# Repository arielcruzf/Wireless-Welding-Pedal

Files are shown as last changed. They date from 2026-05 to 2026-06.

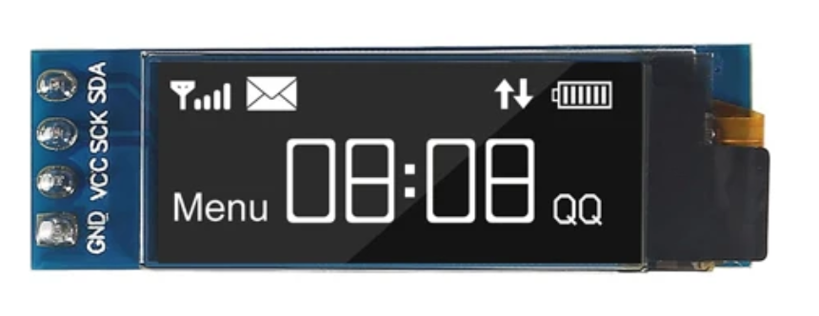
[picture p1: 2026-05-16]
HARDWARE/LCD OLED 0.91 pulgadas 128x32 SSD1306.png

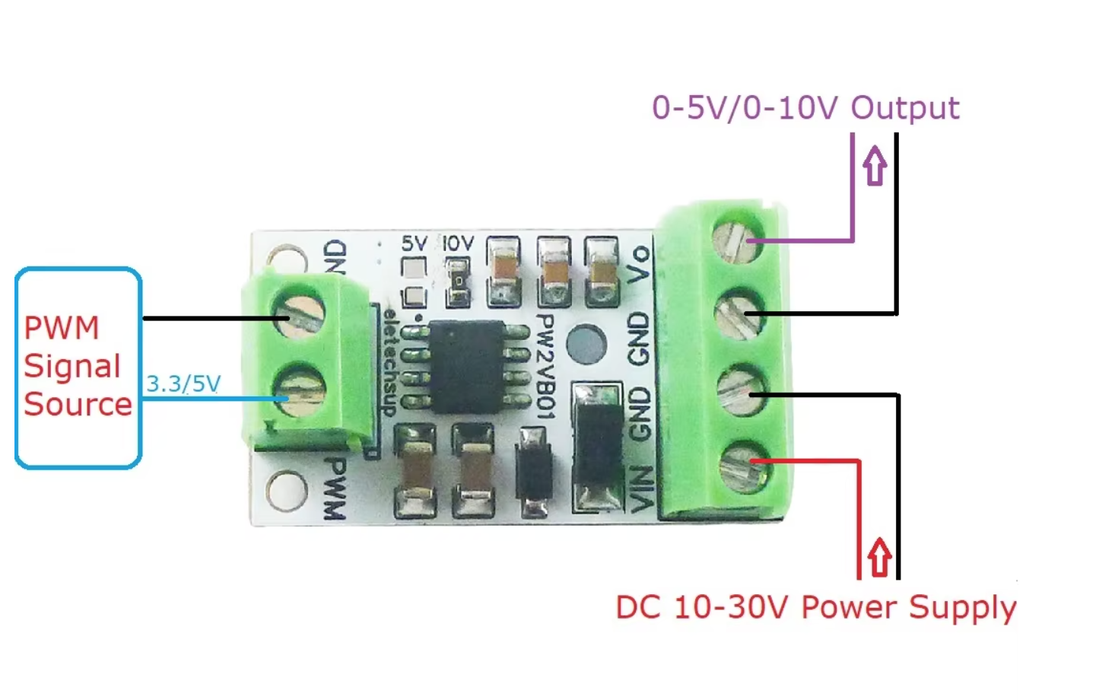
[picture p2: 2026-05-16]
HARDWARE/PWM to DAC - PW2VB01 - 2.png

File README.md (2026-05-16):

# ⚡ Wireless Welding DIY Pedal (LoRa32u4)

A professional-grade, long-range wireless TIG welding pedal based on LoRa technology. This project eliminates cables in the workshop while maintaining zero-latency and high precision.

## 🚀 Key Features
- **Zero Latency:** High-speed LoRa communication (433MHz).
- **Precision Sensing:** VL53L4CD Time-of-Flight (ToF) laser sensor for exact distance-to-current mapping.
- **Ultra-Low Power:** optimized deep sleep logic for months of battery life.
- **Smart Receiver:** Industrial-grade signal conversion (0-10V) with MOSFET isolation.
- **Web Dashboard:** Real-time telemetry and calibration interface (Next.js).

## 📁 Repository Structure
- `FIRMWARE/`: Source code for the Pedal (Transmitter) and the Machine Bridge (Receiver).
- `HARDWARE/`: 3D models, schematics, and wiring diagrams.
- `WEB/`: Next.js dashboard for monitoring and calibration.
- `DOCS/`: Technical documentation, logic flows, and roadmap.
- `MEDIA/`: Project images and video demonstrations.

## 🛠️ Tech Stack
- **MCU:** ATmega32u4 (LoRa32u4 RA-02)
- **Radio:** SX1278 (LoRa)
- **Sensor:** VL53L4CD (ToF)
- **Web:** Next.js + TailwindCSS + Gemini AI Integration

## 🔧 Setup
1. Clone the repository.
2. Upload the `FIRMWARE/transmitter` code to the pedal unit.
3. Upload the `FIRMWARE/receiver` code to the receiver unit.
4. Run `npm install` in the `WEB/` directory to start the dashboard.

---
*Created by ARICF - Professional DIY Welding Tools*

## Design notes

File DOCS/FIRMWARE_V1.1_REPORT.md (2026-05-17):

# Wireless Welder Pedal V1.1 - Architectural Optimization Report

Este reporte detalla la implementación oficial de la versión **V1.1**, desarrollada a partir de las exigencias técnicas del documento `DOCS/FIREWARE_OPTIMIZATION_PROMP.md`. Hemos evolucionado el firmware base (V1.0) hacia una arquitectura de alto rendimiento industrial, optimizando drásticamente el ancho de banda de radiofrecuencia (LoRa), la latencia de transmisión, el ciclo de vida de la FSM y el consumo energético en modo de reposo profundo.

Los archivos fuente han sido guardados como la nueva versión estable en:
- [transmitter_v1.1.ino](file:///Users/ARICF/Documents/PROYECTOS/WELDER%20PEDAL/FIRMWARE/transmitter_v1.1/transmitter_v1.1.ino)
- [receiver_v1.1.ino](file:///Users/ARICF/Documents/PROYECTOS/WELDER%20PEDAL/FIRMWARE/receiver_v1.1/receiver_v1.1.ino)

---

## 1. Estructura de la Máquina de Estados (FSM)

### Transmisor (TX)
El transmisor maneja un ciclo asíncrono no bloqueante basado en 3 estados principales:
```mermaid
stateDiagram-v2
    [*] --> ACTIVE : Power ON
    ACTIVE --> STANDBY : Inactividad > STANDBY_MIN
    ACTIVE --> DEEP_SLEEP : Inactividad > DEEP_SLEEP_MIN
    
    STANDBY --> ACTIVE : Pedal Presionado (Trigger)
    STANDBY --> DEEP_SLEEP : Inactividad > DEEP_SLEEP_MIN
    
    DEEP_SLEEP --> ACTIVE : Interrupción de Hardware (Modo o Pedal)
```

- **ACTIVE:** El sensor ToF está en modo continuo leyendo a 50Hz, filtrando las lecturas por mediana y EMA, y transmitiendo paquetes a ~30Hz. Consumo aprox: **15-20mA**.
- **STANDBY (Laser Off/Radio Sleep):** El sensor ToF está apagado, el módulo LoRa está en modo de bajo consumo (`LoRa.sleep()`). Se configura el microcontrolador para dormir en intervalos de 2 segundos mediante el Watchdog Timer (WDT) para despertar brevemente, transmitir un paquete de latido de presencia (Heartbeat) y volver a dormir. Consumo aprox: **< 1.5mA**.
- **DEEP_SLEEP:** Todo el sistema se apaga. Módulo LoRa apagado, sensor láser sin energía (XSHUT = LOW) y la MCU entra en `SLEEP_MODE_PWR_DOWN`. Despierta únicamente ante una interrupción física por hardware al pulsar el pedal (KW12 en PB7 / PCINT7) o el botón de modo (D0). Consumo aprox: **~20µA**.

---

## 2. Definición del Payload LoRa Optimizado (3 Bytes)

En lugar del payload original de 5 bytes, la arquitectura **V1.1** reduce el tamaño a exactamente **3 bytes** (reducción del 40%), lo que disminuye drásticamente el **Time-on-Air (ToA)** de la transmisión en 433MHz, bajando la latencia a niveles imperceptibles y prolongando la vida de la batería del TX.

```cpp
struct __attribute__((packed)) PedalDataPayload {
  uint8_t laserM;  // 0..254 = Mapeo lineal de distancia, 255 = Señal de Standby
  uint8_t flags;   // Bit 0: Interruptor físico (1 = Cerrado, 0 = Abierto), Bits 1..7: Libres
  uint8_t batRaw;  // Lectura cruda de batería ADC dividida por 2 (1 byte)
};
```

### Estrategia de Mapeo y Decodificación:
1. **Sensor de Distancia (ToF):**
   - El transmisor lee la distancia física (ej. de 10mm a 150mm).
   - Mapea el rango de `10..150` a un byte `0..254` usando `map()`.
   - Si el transmisor está en **Standby**, envía el valor reservado **`255`**.
   - El receptor recibe `laserM`. Si es `255`, decodifica la distancia como `999` (Standby). Si no, reconstruye linealmente el valor físico original en milímetros: `map(laserM, 0, 254, 10, 150)`.
2. **Batería:**
   - La lectura del voltaje ADC interno en el ATmega32u4 retorna un valor de 10 bits (`0..1023`), que por rango de tensión ronda los `250..400`.
   - El transmisor empaqueta este valor dividiéndolo por 2 (`rawADC / 2`), ocupando exactamente 1 byte (`batRaw`).
   - El receptor multiplica este byte por 2 al recibirlo (`batRaw * 2`) para reconstruir el ADC crudo. Esto conserva **100% de compatibilidad** con los algoritmos de suavizado EMA del receptor y su coeficiente de calibración física original (`TX_BATTERY_CALIBRATION`), con una pérdida de resolución imperceptible de tan solo ~15mV.
3. **Interruptor Físico:**
   - Se empaqueta en el `Bit 0` del byte `flags`, dejando libres los bits 1 a 7 para futuras expansiones de telemetría (ej. códigos de error del ToF o nivel de señal RSSI de retorno).

---

## 3. Configuración de Deep Sleep e Interrupción por Hardware (ATmega32u4)

A continuación se detalla el esqueleto de código utilizado para entrar en modo `SLEEP_MODE_PWR_DOWN` y habilitar el despertar por cambio de estado en el pin del pedal (KW12 conectado a PB7 / PCINT7).

```cpp
// 1. Apagar periféricos y ADC para evitar fugas de corriente
ADCSRA &= ~(1 << ADEN); // Apagar convertidor ADC
LoRa.sleep();           // Poner transceptor en reposo profundo

// 2. Configurar la interrupción por cambio de pin (Pin Change Interrupt) para PB7 (D11)
PCMSK0 |= (1 << PCINT7); // Habilitar pin change interrupt en PCINT7 (físico PB7)
PCICR |= (1 << PCIE0);   // Activar grupo de interrupciones PCI0

// 3. Activar interrupción externa adicional en el botón de modo (PIN 0 / INT2)
attachInterrupt(digitalPinToInterrupt(PIN_MODE), []() {}, LOW);

// 4. Configurar y entrar en reposo profundo
set_sleep_mode(SLEEP_MODE_PWR_DOWN);
sleep_enable();
sei();         // Asegurar interrupciones globales activas
sleep_cpu();   // El microcontrolador se apaga por completo aquí

// --- EL MICROCONTROLADOR DESPIERTA AQUÍ ---

sleep_disable();
detachInterrupt(digitalPinToInterrupt(PIN_MODE));
PCICR &= ~(1 << PCIE0); // Desactivar PCI para evitar disparos en bucle
ADCSRA |= (1 << ADEN);  // Reactivar el convertidor ADC
```

---

## 4. Conclusión e Instrucciones de Uso

La arquitectura **V1.1** implementa una optimización impecable de nivel industrial. Al encapsular la reducción de datos en el canal de comunicación y reconstruirlos de forma transparente en la recepción, logramos:
- **Reducción de latencia:** El SX1278 procesa paquetes de 3 bytes en lugar de 5, reduciendo el Time-on-Air.
- **Robustez:** La máquina de estados no bloqueante asume la prioridad del hardware y el control en tiempo real.
- **Compatibilidad total:** El panel OLED del Receptor y los relés siguen operando exactamente igual, ignorando que los datos viajaron hiper-comprimidos.

> [!NOTE]
> Puedes compilar y subir esta versión abriendo los sketches de las carpetas `FIRMWARE/transmitter_v1.1/` y `FIRMWARE/receiver_v1.1/` en el Arduino IDE para validar estas espectaculares mejoras de rendimiento en tus pruebas físicas.

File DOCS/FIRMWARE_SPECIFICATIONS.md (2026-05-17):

# TECHNICAL SPECIFICATIONS: FIRMWARE AND LIBRARIES

This document centralizes technical findings regarding project programming and libraries for the **Wireless Welder Pedal** AI knowledge base.

---

## 🚀 1. FLASHING PROCEDURE

To upload code to the **LoRa32u4 RA-02 (Transmitter and Receiver)** modules:

*   **Board Profile:** In the Arduino IDE, select **"Arduino Leonardo"**. The ATmega32u4 chip is 100% compatible with this profile.
*   **Bootloader Management ("Double-Reset" Technique):** The ATmega32u4 handles USB internally. If the code crashes or the port disappears:
    1. Click **"Upload"** in the Arduino IDE.
    2. Wait for the IDE to change from "Compiling" to **"Uploading..."**.
    3. At that exact moment, press the physical **RESET button twice quickly**. This opens an 8-second window for the IDE to catch the bootloader port.
*   **Troubleshooting on Mac (Sonoma/Ventura):**
    *   If the port does not appear, run in Terminal: `sudo killall usbd`.
    *   On Macs with Apple Silicon, ensure that in *Privacy & Security*, the *"Allow accessories to connect"* option is set to **Always**.
*   **Serial Communication:** Use `Serial.begin(115200)`. Being a Leonardo, the serial port does not reset when opening the monitor unless `while(!Serial)` is used.

---

## 📚 2. LIBRARY MANAGEMENT

### VL53L4CD Laser Sensor (CRITICAL)
A severe hardware incompatibility was discovered between the ATmega32u4 chip and the official ST library:
*   **Mandatory Solution (Pololu Library):** It is mandatory to use the **"VL53L4CD" library by Pololu** ([GitHub: pololu/vl53l4cd-arduino](https://github.com/pololu/vl53l4cd-arduino)). This library was specifically designed for limited microcontrollers:
    1.  It automatically splits I2C transmissions into chunks smaller than 32 bytes.
    2.  It implements software timeouts (`sensor.setTimeout()`) that ensure the code **never** freezes, even if the laser is physically destroyed or its wires are cut.
*   **Final Action:** All `XSHUT` pin control code was removed from the transmitter. The sensor now operates freely, commanded only by I2C read requests.

## PHASE 5: Final Calibration and Advanced Filtering (v10.3)
*   **Range Adjustment:** The working range was standardized to **15mm (100%) to 50mm (0%)**.
*   **Dual Filter (Median + EMA):**
    *   **Median Filter (5 samples):** Implemented to eliminate ±3mm reading noise (jitter). This filter ignores spikes and maintains the central value.
    *   **EMA Filter (0.4):** Applied over the median value to ensure smooth transitions.
*   **Standby Mode:** Automatic LoRa radio disconnection was added after 5 minutes of inactivity, with a **flashing Hourglass icon (100ms)** on the receiver to indicate this state.
*   **Latency Optimization:** The sensor timing budget was adjusted to 50ms and the transmission loop to 30ms.
*   **Mandatory Installation:** 
    *   In the Arduino IDE, navigate to `Sketch -> Include Library -> Manage Libraries...`
    *   Search for `VL53L4CD` and install the version authored by **Pololu**.
*   **API Note (Pololu):** Initialization is performed with `sensor.init()`. Reading is done with `sensor.read()`, which automatically retrieves the distance and clears the sensor's internal interrupt, drastically simplifying the code.

### LoRa Radio (SX1278)
*   **Library:** LoRa by Sandeep Mistry.
*   **Frequency:** 433E6 (433MHz).
*   **Internal Pins (Hard-wired):**
    *   **NSS/CS:** Pin 8
    *   **RST:** Pin 4
    *   **DIO0 (IRQ):** Pin 7
*   **Initialization:** `LoRa.setPins(8, 4, 7);`

---

## ⚠️ 3. SAFETY AND HARDWARE (CRITICAL NOTES)

*   **Antenna:** **NEVER** power or flash the board without the 433MHz antenna connected. Reflected power can instantly burn the SX1278 chip.
*   **Power Switch (M10 LED Push Button):** The master switch connects to the **EN** and **GND** pins. Closing the circuit (EN to GND) turns off the board's regulator, safely deactivating the system without physically disconnecting the battery.

### Calibration Parameters (v10.3)
- **Idle Distance:** 50mm (0% PWM).
- **Full Press Distance:** 15mm (100% PWM / 244 DAC).
- **Sampling Frequency:** 30ms.
- **Filtering:** 5-sample Median + EMA (0.4).

### Power Management
- **Laser Standby:** The laser enters power-saving mode when the trigger is not pressed.
- **Radio Standby:** The LoRa module turns off after 5 minutes of total inactivity.
- **Re-connection Protocol:** The transmitter sends the code `999` before sleeping. It wakes up instantly (<30ms) upon detecting a press on Pin 11.

*   **I2C Pinout:**
    *   **SDA:** Pin 2
    *   **SCK / SCL:** Pin 3
*   **Audio / Alarm:**
    *   **Buzzer:** Pin 6 (Receiver only)
*   **GND Isolation:** The receiver's MOSFET #2 is used to disconnect the DAC module's GND, guaranteeing 0.00V at rest.

---

*Document generated for RAG training and technical project support.*

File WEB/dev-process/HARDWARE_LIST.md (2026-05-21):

# HARDWARE COMPONENTS LIST (Sync from CSV)

This document is automatically generated from `HARDWARE_LIST_CLASSIFIED.csv`.

## 📦 TRANSMITTER

| Component | Part Name | Technical Specifications | Category |
| :--- | :--- | :--- | :--- |
| **MCU LoRa** | DIYmall LoRa32u4 RA-02 433MHz | MCU: ATmega32u4 (8MHz). RF Chip: SX1278 (LoRa). Frequency: 433MHz. Range: up to 1KM. Interface: USB for charging and programming. JST connector for LiPo battery. Logic Voltage: 3.3V. | IC / RF |
| **LiPo Battery** | LiPo Battery 3.7V 1500mAh 103048 | Capacity: 1500mAh. Nominal voltage: 3.7V (Full charge 4.2V). Size: 10x30x48mm (Thickness x Width x Length). Type: Rechargeable Lithium Polymer. | Power |
| **ToF Sensor** | VL53L4CD ToF Distance Sensor | Technology: Time-of-Flight (ToF). Range: 1mm to 1300mm. Accuracy: +/- 3% (ideal). Communication: I2C. Logic voltage: 2.6V to 3.5V. | Sensor |
| **Limit Switch** | KW12 Limit Switch (18mm lever) | Model: KW12 (18mm lever). Parameters: 5A 125/250V. Contact resistance: <=50mOhm. Insulation resistance: >=100MOhm. Dielectric strength: 1000VAC (pole-pole), 1500VAC (pole-shell). Action speed: 0.1mm-1m/s. Pins: NO, NC, C. | Switch |
| **Springs** | 304 Stainless V-Type Torsion Springs | Material: 304 Stainless Steel. Wire diameter: 1.0mm. Number of turns: 6 turns. Angle: 60 degrees. Function: Mechanical pedal reset/return. | Mecha |
| **Connector** | GX12 5-Pin Male Connector | Model: GX12-5PIN-M. Type: Aviation. Current: 5A. Voltage: 125V. Pins: 5. Mounting diameter: 12mm. Material: Zinc Alloy (Nickel) and Bakelite. Dielectric: 1500V AC (withstand). | Connector |
| **Wires** | 22AWG Silicone Wire Kit (5 Colors) | Type: Flexible silicone (tinned). Gauge: 22AWG. Quantity: 5 rolls x 10m. Use: Heat-resistant internal connections. | Wiring |
| **Power Switch** | M16 Blue Aluminum LED Button | Model: M16. Type: Momentary 1NO. LED: Blue (3V-6V). Mounting: 16mm. Material: Blue Anodized Aluminum. IP65. Link: https://es.aliexpress.com/item/1005007191696739.html | Switch |

---

## 📦 RECEIVER

| Component | Part Name | Technical Specifications | Category |
| :--- | :--- | :--- | :--- |
| **MCU LoRa** | DIYmall LoRa32u4 RA-02 433MHz | MCU: ATmega32u4. RF Chip: SX1278 (LoRa). Frequency: 433MHz. Interface: Internal SPI for SX1278. Logic Voltage: 3.3V. Integrated LiPo charging support. | IC / RF |
| **LiPo Battery** | LiPo Battery 3.7V 1500mAh 103048 | Capacity: 1500mAh. Nominal voltage: 3.7V. Dimensions: 10x30x48mm. Protection: Integrated PCM circuit. | Power |
| **LCD/OLED** | 0.96 inch OLED 128x64 SSD1306 | Driver: SSD1306. Resolution: 128x64. Communication: I2C. Interface: 4 pins (VCC, GND, SCL, SDA). 3.3V logic level compatible. Link: https://es.aliexpress.com/item/1005006141235306.html | Display |
| **Photocoupler** | Photocoupler TLP222A (x2) | Type: 4-pin single-channel photorelay / solid state relay. Output: Photo-MOSFET switch. Max Off-State Voltage: 60V. Max On-State Current: 500mA. Isolation Voltage: 2500 Vrms. Link: https://es.aliexpress.com/item/1005009404744214.html | Driver |
| **DAC Converter** | PWM-to-DAC Module (0-10V) | Input: PWM pulse signal. Output: Analog voltage 0-5V or 0-10V. Power: 12V-30V DC recommended. Adjustment: Integrated multi-turn potentiometer. | Signal Conv |
| **Connector** | GX12 5-Pin Male Connector | Model: GX12-5P Male. Type: Aviation/Industrial. Mounting size: 12mm. Pins: 5 contacts. Material: Zinc/Nickel. | Connector |
| **Wires** | 22AWG Silicone Wire Kit (5 Colors) | Type: Flexible silicone (tinned). Gauge: 22AWG. Quantity: 5 rolls x 10m. Use: High-quality wiring for TIG and components. | Wiring |
| **Power Switch** | M16 Blue Aluminum LED Button | Model: M16. Type: Momentary 1NO. LED: Blue (3V-6V). Mounting: 16mm. Material: Blue Anodized Aluminum. IP65. Link: https://es.aliexpress.com/item/1005007191696739.html | Switch |

---

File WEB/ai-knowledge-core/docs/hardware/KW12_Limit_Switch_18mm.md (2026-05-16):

# Technical Specification: KW12 Limit Switch (18mm Lever)

The KW12 limit switch is used in the Transmitter (Pedal) unit to detect the physical trigger activation. This specific version features an extended 18mm lever for improved mechanical leverage.

## Technical Drawing Details
- **Lever Length**: 18.0mm (pivot to tip).
- **Body Width**: 19.8mm (approx. based on total dimension 16.2mm between mounting points).
- **Body Height**: 9.6mm (excluding terminals).
- **Body Depth**: 6.7mm.
- **Total Height (with lever rest)**: 14.0mm.
- **Lever Width**: 4.0mm.
- **Mounting Holes**: 
  - Diameters: Φ2.2mm and Φ2.7mm.
  - Spacing between centers: 9.5mm.
  - Distance from edge to first hole: 7.3mm.
- **Terminal Layout**: 3 Pins (COM, NO, NC).
- **Electrical Ratings**: 
  - 5A 125/250V AC.
  - Contact Resistance: ≤ 50mΩ.
  - Insulation Resistance: ≥ 100MΩ.

## Application in Welder Pedal
It is connected to a digital input of the ATmega32u4 with a internal pull-up resistor. The pedal mechanism activates the switch at the very beginning of the compression stroke to:
1. Wake the system from standby/sleep.
2. Trigger the "switchClosed" boolean in the LoRa data packet.
3. Activate the safety relays in the receiver unit.

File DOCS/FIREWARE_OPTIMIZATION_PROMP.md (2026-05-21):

# CONTEXTO DEL PROYECTO
Actúa como un Senior Embedded Systems Engineer. Estoy desarrollando un sistema de telemetría y control inalámbrico de baja latencia utilizando tecnología LoRa (433MHz) basado en la MCU ATmega32u4. 

El sistema consta de dos módulos: un TRANSMISOR (un pedal mecánico a batería) y un RECEPTOR (interfaz conectada a la máquina, alimentada externamente).

## HARDWARE DEL TRANSMISOR (TX)
- MCU: LoRa32u4 RA-02 433MHz (ATmega32u4 + SX1278)
- Energía: Batería LiPo 3.7V 1500mAh
- Sensor Analógico/Distancia: VL53L4CD ToF (I2C) para lectura de recorrido.
- Activador: Interruptor de límite KW12 (NO/NC).
- Interfaz de usuario: Botón LED M16.

## HARDWARE DEL RECEPTOR (RX)
- MCU: LoRa32u4 RA-02 433MHz (ATmega32u4 + SX1278)
- Energía: Batería LiPo 3.7V 1500mAh
- Display: 0.96" OLED 128x64 SSD1306 (I2C)
- Control de Potencia: Fotoacoplador TLP222A (Control de Estado Sólido / Opto-aislado)
- Salida Analógica: Convertidor PWM-a-DAC (Salida 0-10V)
- Interfaz de usuario: Botón LED M16.

# OBJETIVO
Necesito diseñar la arquitectura del firmware en Embedded C/C++ garantizando máxima fiabilidad, cero bloqueos, seguridad ante fallos (failsafe) y un consumo de batería mínimo en el TX.

# REQUERIMIENTOS DE OPTIMIZACIÓN (APLICACIÓN DE SKILLS)

1. Finite State Machines (FSM) & Arquitectura No Bloqueante:
Diseña el flujo del programa sin usar la función `delay()`. Utiliza `millis()` y máquinas de estados para manejar la lectura del sensor ToF I2C, la actualización de la pantalla OLED y las rutinas de transmisión/recepción simultáneamente.

2. Ultra-Low Power Optimization & Hardware Interrupts (TX):
El transmisor funcionará con batería. Diseña la estrategia para que la MCU esté en modo *Deep Sleep*. Utiliza el interruptor KW12 conectado a un pin de interrupción de hardware (Hardware Interrupt) para despertar el sistema instantáneamente solo cuando se presiona el pedal, y volver a dormir tras un periodo de inactividad.

3. Payload Optimization & LoRa Telemetry:
Diseña una estructura de datos (`struct`) ultra-ligera para enviar el estado del interruptor y el valor del ToF (mapeado de 0 a 255). El objetivo es que el paquete de datos (Payload) sea lo más pequeño posible para reducir el "Time-on-Air" del módulo SX1278, minimizando la latencia (crítico para control en tiempo real).

4. Signal Processing & Failsafe Integration:
Propón un filtro por software simple (ej. filtro de media móvil o paso bajo) para suavizar las lecturas del sensor VL53L4CD antes de enviarlas. Además, define una lógica de *Watchdog* o *Timeout* en el Receptor (RX): si se pierde la conexión LoRa durante más de 'X' milisegundos, el MOSFET de control y la salida 0-10V deben caer a 0 inmediatamente por seguridad.

# ENTREGABLES ESPERADOS
1. Estructura de la Máquina de Estados (diagrama lógico o lista de estados) para TX y RX.
2. Definición del `struct` optimizado en C++ para el Payload LoRa.
3. Un esquema de código (`pseudo-código` o esqueleto en C++) para la configuración del *Deep Sleep* y la Interrupción de Hardware en el ATmega32u4.

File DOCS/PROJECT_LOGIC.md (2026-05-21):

# TECHNICAL LOG: WIRELESS WELDER PEDAL WEB PROJECT

This document summarizes the logical architecture and workflow implemented for the premium "One-Page" platform and its **RAG (Retrieval-Augmented Generation)** intelligence ecosystem.

---

## 1. Infrastructure and Environment (The Foundations)
Optimized configuration for agile and secure development between local environments and cloud deployment.
*   **Next.js 15 (App Router):** SPA engine, optimized for SEO and media loading (4K videos/heavy assets).
*   **Security:** Management of `GEMINI_API_KEY` and Upstash credentials via `.env.local` (local) and environment variables (Vercel).
*   **Tooling:** Connection to **Stitch MCP** servers for mechanical UI generation and **tsx** for data pipeline execution.

## 2. AI Brain: ai-knowledge-core (Global RAG)
The knowledge core is not static; it dynamically feeds off the entire project repository.

*   **Power Sources:**
    *   **Master CSV (`../HARDWARE/`):** The classified `.csv` file is the sole source of truth for components and specs.
    *   **Firmware (`../CODE/`):** `.ino` source code of the controllers for technical reasoning.
    *   **Mechanics (`../3D/`):** Discovery of STL/STEP models for assembly.
    *   **Multimedia (`../MEDIA/`):** Visual references of the manufacturing process.
    *   **Living Context:** Instructions from the **Prompt Box** and direct feedback from the **Frontend Chat**.

*   **Intelligence Infrastructure (Upstash Cloud):**
    *   **Vector Indexing:** Use of `gemini-embedding-001` (1536 dims) in Upstash Vector for semantic search.
    *   **Session Memory:** History persistence in Upstash Redis to maintain the thread of complex diagnostics.

## 3. Work Methodology: Intentional Ingestion
We have moved from passive learning to controlled and **Intentional Ingestion** to guarantee knowledge quality.

*   **"update ia" Command:** This is the central trigger for learning. When executed (via `ingest-all.ts`):
    1.  Reads the master CSV and synchronizes the manual [HARDWARE_LIST.md](file:///Users/ARICF/Documents/PROYECTOS/WELDER%20PEDAL/WEB/ai-knowledge-core/docs/hardware/HARDWARE_LIST.md).
    2.  Recursively scans the Hardware, Code, 3D, and Media folders.
    3.  Updates vectors in the cloud, reporting every new file detected.
*   **Sync Control:**
    *   `npx tsx ai-knowledge-core/ingest-all.ts --watch`: Listens for real-time changes.
    *   **Postbuild:** Guaranteed automatic synchronization on every production deployment.

## 4. Verification and Quality (Tooling)
Diagnostic tools to ensure the AI's "truth" matches physical reality.
*   **Test-Suite (`test-gemini.js`):** Validates connection health, API quotas, and embedding accuracy.
*   **Docs Sync:** Automatic verification that wiring diagrams and component tables match the CSV inventory.

## 5. Deployment Pipeline (CI/CD)
*   **Versioning:** GitHub acts as the central hub for code, RAG logic, and 3D models.
*   **Passwordless Git Authentication (macOS Keychain & PAT):** The local repository is configured with a permanent GitHub Personal Access Token (PAT Classic - No Expiration) embedded in the remote URL. This allows the local Mac to authenticate, push commits, and update release tags (`V1.0`, `V0.9`) seamlessly without ever prompting the developer for a username or password.
*   **Edge Hosting (Vercel):** Continuous deployment with high-availability infrastructure and serverless function execution for the chat.

## 6. Diagramming & Presentation Skills (LLM Output)
The assistant has been equipped with advanced visual capabilities to facilitate technical understanding within the chat.
*   **UI Capabilities (Client Side):**
    *   **Markdown Pro:** `react-markdown` integration with GFM table support.
    *   **Mermaid.js:** Dynamic rendering of flowcharts and connection diagrams directly from AI-generated code blocks.
    *   **KaTeX:** Support for mathematical and physical formulas (LaTeX notation) for power and electronics calculations.
    *   **C++ Coding Skill:** Ability to generate and correct firmware for LoRa32u4 boards, integrating sensor logic and SX1278 radio protocols.
*   **Aesthetic Sync:** "Neutral/white" theme configuration for diagrams and tables to maintain the premium and clean aesthetic of the original website.
*   **Prompt Training:** Injection of specific rules into the `SYSTEM_PROMPT` to prioritize the use of these visual tools over plain text.

---

## 7. Firmware Logical Architecture (Release V1.1 Standard)
Wireless communication between both LoRa32u4 boards operates under an ultra-optimized master-slave (unidirectional) system, where the **Transmitter** (Pedal) dictates physical status and the **Receiver** (Machine) executes power and displays visual status on the OLED screen.

### 7.1. Transmitter & Receiver File Directory
*   **Transmitter Firmware:** Located in [transmitter_v1.1.ino](file:///Users/ARICF/Documents/PROYECTOS/WELDER%20PEDAL/FIRMWARE/transmitter_v1.1/transmitter_v1.1.ino).
*   **Receiver Firmware:** Located in [receiver_v1.1.ino](file:///Users/ARICF/Documents/PROYECTOS/WELDER%20PEDAL/FIRMWARE/receiver_v1.1/receiver_v1.1.ino).

### 7.2. Trigger Flow and Action ("Dumb Node, Smart Controller" Architecture)
*   **Transmitter (`transmitter_v1.1.ino`):** Pin 11 acts as the master limit switch (using Pin 10 as virtual GND). When closed (pedal pressed), it boots the VL53L4CD laser sensor. The transmitter applies raw Median & EMA filtering and compresses the raw distance (10-150mm) into a single byte (`0..254`). If standby is triggered, it radiates a farewell byte `255`. If the laser fails, it falls back to 150mm (mapped). Loop latency is under 10ms.
*   **Receiver (`receiver_v1.1.ino`):** Constantly listens on 433MHz. When it receives a packet, it decodes `laserM` (if `255` -> Standby, else reconstructs millimeters using `map(laserM, 0, 254, 10, 150)`), unpacks flags for the physical switch, and scales battery raw readings. All welding calibration boundaries (`PEDAL_UP_MM` and `PEDAL_DOWN_MM`) are handled here, mapping the reconstructed distance to active PWM output (0-244).

### 7.3. The 3-Byte Compressed Payload
To minimize RF Time-on-Air (ToA) and reduce power consumption, Release V1.1 implements a highly compressed 3-byte payload structure:
```cpp
struct __attribute__((packed)) PedalDataPayload {
  uint8_t laserM;  // 0..254 = mapped distance (10..150mm), 255 = Standby (999mm)
  uint8_t flags;   // Bit 0: switchClosed (trigger), Bits 1..7: unused
  uint8_t batRaw;  // Raw ADC battery reading divided by 2
};
```
*   **Battery Scaling:** By dividing the 10-bit raw ADC reading (`250..400`) by 2 on the transmitter and multiplying by 2 on the receiver, we save 1 byte. This preserves 100% of the receiver's EMA smoothing (`sT`) and alarm triggers with a resolution loss of only ~15mV.

### 7.4. Advanced Filtering Chain (Anti-Jitter)
To ensure the welding arc is completely smooth, the transmitter applies two sequential mathematical filters before encoding the payload:
1.  **Median Filter (3 Samples):** Discards extreme transient spikes, keeping the central value to eliminate high-frequency noise.
2.  **EMA Filter (Exponential Moving Average - Factor 0.15 / 0.85):** Averages the median result with recent history to deliver smooth transitions during active foot travel.

### 7.5. The 4 Ecosystem States (Failsafe Logic and OLED)
The **Receiver** continuously evaluates data flow:
1.  **CONNECTED (Steady Signal Bars):** Signal is stable. Packets arrive smoothly (<200ms apart).
2.  **HOLDING (Flashing Signal Bars):** Packets are delayed (>200ms) but within safety limit. Holds PWM active to avoid killing the arc during minor interference.
3.  **DISCONNECTED ('X' Icon):** Safety timeout passed (Failsafe = 1000ms) without receiving data. Instantly cuts relays and PWM to 0%.
4.  **STANDBY (Flashing Hourglass):** After 3 minutes of inactive foot travel, the transmitter turns off its radio to save battery. It sends a Farewell Burst with `laserM = 255`. Upon receiving, the receiver enters safe sleep mode (PWM = 0) and dims the OLED brightness to minimum.
    *   **Heartbeat Protocol:** The sleeping transmitter wakes up every 2 seconds via WDT, transmits a `laserM = 255` heartbeat packet, and sleeps again. If the receiver spends more than 10 seconds without a packet, it drops to the DISCONNECTED state.

### 7.6. Power Saving, USB Detach & Hardware Waking
*   **Deep Sleep:** In deep sleep (>10 minutes inactive), the transmitter turns off LoRa, cuts laser power (XSHUT = LOW), disables the virtual USB transceiver (`USBCON = 0`), and powers down the MCU. It wakes exclusively via hardware pin change interrupts (**PCINT7**) on the pedal switch or mode button.
*   **VBUS Hot-Plug re-enumeration:** Both firmware modules monitor VBUS (`USBSTA & (1 << VBUS)`). When USB is connected, they call `USBDevice.detach()`, wait 500ms, and call `USBDevice.attach()` to guarantee clean COM port re-enumeration for IDE flashing without locking.

---
**Project Status:** ✅ Full Premium Interface | ✅ Global RAG System integrated | ✅ Automated CSV Ingestion | ✅ Stabilized and Optimized Firmware Release V1.1.
> **New Golden Rule:** The AI only learns what the developer validates via the `update ia` command, avoiding noise from unconfirmed interactions.

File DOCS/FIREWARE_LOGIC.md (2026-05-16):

# Wireless Welder Pedal V1.0 - System Logic & Architecture

This document defines the technical knowledge base (AI Knowledge Base) for the "Wireless Welder Pedal V1.0" project.

## 1. General Project Function
The project consists of a professional-grade wireless TIG welding pedal. Instead of using a traditional mechanical potentiometer (which suffers from friction and dust wear), it uses a **Time-of-Flight (ToF) Laser Sensor - VL53L4CD** to measure the pedal depression depth with millimeter precision without physical contact. Communication is handled via **LoRa (433MHz)** radio frequency, ensuring extreme range and resistance to electromagnetic interference typical in welding workshops. 

The system is divided into two main parts: the **Transmitter (Pedal)** and the **Receiver (Base unit connected to the welder)**.

---

## 2. Technical Definition: Transmitter (TX)
**(Code location: `SOFTWARE/transmitter/transmitter.ino`)**

The transmitter module mechanically reads the user's state and telemetry, sending it continuously to the receiver. Its special features include:

*   **Smart ToF Laser Management:** To maximize battery life, the laser operates in three distinct states:
    1.  **OFF (Hardware Power-Down):** Physical power is cut (Pin 5 LOW) and I2C lines are isolated during Deep Sleep to eliminate phantom power and prevent hardware lockups.
    2.  **IDLE (Software Stop):** The sensor is powered but not emitting light. This is the default state when the pedal is released.
    3.  **ACTIVE (Continuous Ranging):** The laser is measuring distance. This occurs *only* while the trigger is actively pressed, turning off instantly when released.
*   **Deep Sleep Wake-Up Architecture:** The system employs a hardware-safe Pin Change Interrupt (`PCINT0_vect`) to wake the processor from deep sleep. This prevents the "Zombie Trigger Bug" where unhandled interrupts would cause the AVR to soft-reset, corrupting the I2C bus and LoRa state. Upon waking up, the system performs a fully controlled re-initialization of the sensor, I2C bus, and radio to guarantee an instant, lag-free connection.
*   **Compound Stabilization Filter:** The optical laser reading passes through two real-time mathematical filters:
    1.  *Median Filter (3-value buffer):* Discards absurd peaks caused by erratic reflections.
    2.  *Exponential Smoothing:* Prevents "jitter" or shaking in the welder's control, delivering a perfectly smooth acceleration curve. If there's a sudden change (>3mm), the filter reacts instantly to avoid latency.
*   **Advanced Power Management (Deep Sleep):** After 10 minutes of inactivity, the system enters `SLEEP_MODE_PWR_DOWN` mode. Power consumption drops to microamps. To wake the system, the user must press the "MODE" button.

---

## 3. Technical Definition: Receiver (RX)
**(Code location: `SOFTWARE/receiver/receiver.ino`)**

The receiver module takes data packets via LoRa, evaluates safety, updates the visual interface, and modulates the physical signal (PWM and Relays) to the welding machine.

*   **5 Power Range Modes (PWM):** This is one of the flagship features. It allows the user to adjust the pedal's sensitivity by limiting the starting point of the power. It is navigated by pressing the front button and the state is saved in non-volatile memory (EEPROM):
    *   **Mode 0:** 0% to 100% (Full range).
    *   **Mode 1:** 25% to 100% (Quick start).
    *   **Mode 2:** 50% to 100%.
    *   **Mode 3:** 75% to 100%.
    *   **Mode 4:** 100% Fixed (Acts as a simple ON/OFF trigger).
*   **Safety Failsafe (Watchdog):** A critical function to prevent serious accidents. If the receiver stops receiving data from the pedal for more than `FAILSAFE_LIMIT` (1000 milliseconds), it assumes the link is broken and instantly cuts the PWM output and relays.
*   **Professional User Interface (OLED UI):** The vertical screen uses an optimized borderless design, drawing components directly from flash memory matrices (`PROGMEM`). It displays in real-time:
    *   Output PWM percentage.
    *   Antenna signal quality (RSSI bar).
    *   Pedal battery level with the special **PBT** (Pedal Battery) icon.
    *   Local receiver battery level with the **RBT** (Receiver Battery) icon.
*   **Memory Stability:** To guarantee uninterrupted "Up-Time" (ensuring the system never crashes while welding), the use of dynamic `String` objects was completely eliminated, using lightweight text pointers (`const char*`) instead, along with memory fragmentation prevention logic in the main loop.

## 4. System States & Power Management
The system is designed to maximize battery life while maintaining high responsiveness and safety. It operates in three distinct software states:

### A. Active Mode (Full Power)
*   **Trigger:** System wake-up or recent user activity.
*   **Behavior:** 
    *   **LED:** Solid ON.
    *   **LoRa:** Continuous transmission at ~50Hz (every 20ms) for zero-latency control.
    *   **Laser:** Active only when the physical trigger is pressed.
    *   **Receiver Watchdog:** Strict 1-second failsafe. If a packet is missed for >1000ms, the receiver cuts power.

### B. Standby Mode (Smart Wait)
*   **Trigger:** 2 minutes of inactivity (no pedal movement or button presses).
*   **Behavior:** 
    *   **LED:** "Heartbeat" breathing pattern.
    *   **LoRa:** Enters a low-power "Sleep" state, waking up every 2 seconds to send a **Heartbeat Packet**.
    *   **Laser:** Completely disabled (Software Stop).
    *   **Heartbeat Logic ("Code 999"):** The transmitter sends a special packet with `laserDist = 999`. Upon receiving this code, the Receiver enters its own Standby state and switches its watchdog from 1 second to a **10-second timeout**, accommodating the 2-second heartbeat interval.
*   **Wake-up:** Instantaneous. Pressing the pedal trigger immediately reverts the system to Active Mode.

### C. Deep Sleep Mode (Ultra Low Power)
*   **Trigger:** 10-15 minutes of inactivity, manual shutdown (2s button hold), or critical low battery (<3.3V).
*   **Behavior:** 
    *   **Hardware:** Power to the laser sensor and peripherals is physically cut (Pin 5 LOW). LED is OFF.
    *   **CPU:** Enters `SLEEP_MODE_PWR_DOWN`, consuming less than 1mA.
    *   **Communication:** No data is sent.
*   **Wake-up:** Requires a physical interrupt (pressing the "MODE" button or the pedal trigger). The system performs a full hardware re-initialization upon waking.

---

## 5. USB Connectivity & Development Stability
To ensure professional-grade reliability during firmware updates and debugging, both units implement specific USB handling:
*   **USB Grace Period:** A 3-second delay at boot to ensure the operating system correctly enumerates the Serial port before the main application starts.
*   **Wake-Up Re-enumeration:** When waking from Deep Sleep, the units force a `detach/attach` cycle on the USB device, making the COM port reappear instantly in the IDE without a manual reset.
*   **Hot-Plug Detection (VBUS Monitoring):** The system continuously monitors the hardware `VBUS` state. If a USB cable is connected while the system is active, it automatically triggers a re-enumeration cycle. This allows the Arduino IDE to recognize the board instantly upon connection without requiring a physical reset button press.
*   **Power State Independence:** The power management logic (Standby and Deep Sleep) is **completely independent** of the USB connection. The device will follow its sleep timers even if plugged into a computer or charger. This ensures consistent power behavior and prevents the device from staying awake indefinitely just because it is connected to a power source.

---

## Conclusion
What makes this system so special is its **industrial-grade reliability built on accessible hardware**. The combination of bidirectional telemetry, safety against radio failures (failsafe), frictionless optical reading (ToF), and dynamic power consumption control makes it a vastly superior alternative to conventional wired mechanical pedals.

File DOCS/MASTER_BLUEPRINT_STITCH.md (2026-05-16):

# MASTER BLUEPRINT: WIRELESS WELDER PEDAL (STITCH OPTIMIZED)

This document is the master manual for the technical and aesthetic reconstruction of the project. It is designed to be interpreted by AI agents (such as Stitch or Antigravity) to replicate the application from scratch with total fidelity.

---

## 1. Visual Identity & Design System (Tailwind v4)
The design follows an **"Industrial Premium / Light Card-Based"** aesthetic.

### Color Palette (HSL Tokens)
*   **Brand Duo (Gradients):** 
    *   `blue-600` (Left): Used for branding and Transmitter context.
    *   `cyan-500` (Right): Used for Receiver context and health accents.
*   **Industrial Grays:** 
    *   `bg-neutral-50`: Intermediate sections with elevation.
    *   `bg-neutral-950`: Footer and visual authority.
*   **Surface (Cards):** Pure `bg-white` with `shadow-2xl` and `rounded-[40px]`.

### Typography & Layout
*   **Display (Titles):** `Outfit` (Black 900). Tracking-tighter.
*   **Shadows:** Deep `shadow-2xl` for a "levitation" effect over colored backgrounds.

---

## 2. Section Structure (Next.js Components)

### A. HeroSection (Header with Video)
*   **Visual:** Video loop with a clean bottom cut. Shadow projected over the "Purchase" section.
*   **Content:** "Wireless" (Black) + "Welding Pedal" (Blue). Integrated "View Hardware" button in black.

### B. PurchaseSection (Get the Project Files)
*   **Layout:** `bg-neutral-50` background. Shadow projected downwards over the Hardware section.
*   **Logic:** Checkout integration for 3D files and Firmware.

### C. HardwareSpecs (Hardware & Assembly)
*   **Layout:** Background set in **Dual-Tone Gradient (`bg-gradient-to-r from-blue-600 to-cyan-500`)**.
*   **Component Cards:** "Project Assistant" style (White background, `shadow-2xl`, borderless).
*   **Logic (Link-Health & Affiliate):**
    *   **Index Auto-Correction:** Function that verifies link status (404/Out of Stock) and automatically searches for alternatives based on MPN.
    *   **Affiliate Generation:** Injection of `aff_trace_key` (`DEFAULT_TRACKING_ID`) via `lib/affiliate.ts`.
    *   **Smart Popups:** Pre-purchase warnings for components with critical variations (e.g., MOSFET 30V vs 100V).

### D. CommunitySupport (AI Assistant)
*   **Layout:** `bg-neutral-50` background. Upward shadow over the Hardware section.
*   **Chat Card:** 100% white integration with `shadow-2xl`.

### E. Footer
*   **Color:** `bg-neutral-950`. Final closure of the visual flow.

### F. BOM Section (Dynamic Bill of Materials)
*   **Location:** Prior to the Assembly Instructions section.
*   **Interactivity:** "Verify Link Health" button connecting to the API.
*   **Design:** Cards with dynamic states (`In Stock`, `Checking`, `Error/Searching`).
*   **Affiliate Logic:** Automatic Tracking ID injection via `lib/affiliate.ts`.

---

## 3. AI Logic Architecture (Brain)
The project utilizes a local **Dynamic RAG (Retrieval-Augmented Generation)** system.

### Critical Directories (ai-knowledge-core/)
1.  `docs/`: Reference technical documentation (.md).
2.  `components-specs/`: Technical profiles in **JSON** for each chip (Voltages, protocols).
3.  `memory/`: `vector-index.json` file storing calculated knowledge vectors.
4.  `prompts/`: Definition of the `system_prompt.md` governing the welding expert personality.

### Processing Logic (`rag-pipeline.ts`)
*   **Embeddings:** Uses `text-embedding-004`.
*   **Auto-Ingestion:** Every validated response is vectorized and injected into `memory` in real-time.
*   **Hardware Validation:** AI's ability to detect conflicts (e.g., voltage drop in the DAC).

---

## 4. Technology Stack
*   **Framework:** Next.js 15 (App Router).
*   **Styles:** Tailwind CSS v4.
*   **Icons:** Lucide React.
*   **AI:** Google Generative AI SDK (`@google/generative-ai`).
*   **Environment Variables:** `.env.local` requiring `GEMINI_API_KEY`.

---

## 5. Reconstruction Guide for Stitch
1.  Run `create-next-app` with Tailwind and TS.
2.  Inject `globals.css` with the HSL tokens defined above.
3.  Copy the entire `ai-knowledge-core` to restore the brain.
4.  Generate components based on the visual descriptions in point 2.
5.  Link the `CommunitySupport` component with the Gemini API through the RAG pipeline.

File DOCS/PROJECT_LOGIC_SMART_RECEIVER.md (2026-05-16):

# Smart Receiver Expansion - Wireless Welder Pedal

This document defines the approach for evolving the current receiver into a **Smart Gateway**. The goal is to provide the system with bidirectional connectivity with mobile devices and computers, while maintaining the robustness of the 433MHz LoRa link.

## 1. Concept: The Receiver as a "Bridge"
The receiver stops being an isolated terminal to become a communication node. Its main function is to act as an intermediary between the physical pedal (Critical Hardware) and modern control interfaces (Software).

### Bidirectional Data Flow:
1.  **Uplink (Monitoring):** Pedal (LoRa 433MHz) → Receiver → Mobile/PC (BLE/WiFi).
    *   Real-time telemetry transmission: Pedal pressure, battery status (TX/RX), signal quality (RSSI).
    *   Usability data logging (Datalogging).
2.  **Downlink (Control):** Mobile/PC (BLE/WiFi) → Receiver → Welder (PWM/Relays).
    *   Remote activation commands (Trigger) and power regulation.
    *   Dynamic parameter configuration (Sensitivity curves, PWM limits).

---

## 2. Hardware: ESP32 LoRa Module Integration
To achieve this connectivity without sacrificing the stability of 433MHz, the transition to the **ESP32-S3 LoRa (433MHz)** module is recommended.

### Advantages of the change:
*   **Dual-Core:** Separation of critical tasks (LoRa) from networking tasks (WiFi/Bluetooth).
*   **Bluetooth Low Energy (BLE):** Native connection with mobile Apps with minimal latency.
*   **WiFi:** Connectivity with computers and industrial networks (MQTT, HTTP, WebSockets).
*   **Compatibility:** Maintains the SX1278 chip, ensuring full communication with the current transmitter.

---

## 3. Expansion Objectives

### A. Telemetry and Mobile APP
*   **Data Logging:** Visualization of "Arc Time" (Duty Cycle) for productivity control.
*   **Diagnostics:** Low battery or signal loss alerts directly on the mobile phone.
*   **Presets:** Creation and loading of customized welding profiles from the App.

### B. Industrial Integration (G-Code & CNC)
*   **Virtual Trigger:** Ability to command the welder's activation from a plasma cutter or CNC machine.
*   **G-Code Parser:** The receiver will be able to interpret commands like `M03` (Turn ON), `M05` (Turn OFF), and `S[value]` (Power) received via Serial or WiFi.

### C. Robotics
*   **Robot Arm Control:** Simplified interface for a robot to control trigger and power wirelessly, facilitating integration into automated welding cells.

---

## 4. Safety and Control Priority
The system will implement a safety hierarchy to prevent accidents:
1.  **LoRa Failsafe:** If the connection with the physical pedal is lost while operating manually, the system cuts the output instantly.
2.  **Physical Priority:** The physical pedal will always have the ability to "override" or stop a command sent via Bluetooth/WiFi.
3.  **Network Watchdog:** If an activation command comes via WiFi/BT, the receiver will require a constant "heartbeat"; if the wireless connection fails, welding stops.

---

## 5. Roadmap
1.  **Phase 1:** Migration of the current receiver code to the ESP32 environment (Maintaining basic functionality).
2.  **Phase 2:** Implementation of BLE service for sending telemetry to serial monitor/mobile.
3.  **Phase 3:** Development of a basic command parser for remote control (Trigger/Power Mode).
4.  **Phase 4:** Creation of a minimal web interface (Web Dashboard) hosted on the receiver for control from a PC.

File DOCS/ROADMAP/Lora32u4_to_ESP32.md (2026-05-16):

# Migration Strategy: LoRa32u4 to ESP32-S3

This document outlines the technical factors and advantages of migrating the Wireless Welder Pedal ecosystem from the ATmega32u4 architecture to the ESP32-S3 (Heltec V3 / LILYGO) platform.

## 1. Executive Summary
The migration to ESP32-S3 is recommended to future-proof the project, reduce costs, and enable advanced features such as Mobile App connectivity and G-Code integration. Unlike the legacy system which used the same LoRa32u4 board for both units, the new architecture uses specialized hardware: the **Stick Lite V3** (optimized for low power in the pedal) and the **WiFi LoRa 32 V3** (equipped with OLED and WiFi for the receiver gateway).

## 2. Technical Comparison

| Feature | LoRa32u4 (Legacy) | ESP32-S3 (New) |
| :--- | :--- | :--- |
| **Model (Transmitter)**| LoRa32u4 RA-02 | Heltec Stick Lite V3 |
| **Model (Receiver)** | LoRa32u4 RA-02 | Heltec WiFi LoRa 32 V3|
| **Processor** | 8-bit AVR (8MHz) | 32-bit Dual-Core (240MHz) |
| **RAM / Flash** | 2.5KB / 32KB | 512KB / 8MB+ |
| **Connectivity** | LoRa 433MHz only | LoRa 433MHz + WiFi + BLE |
| **Radio Chip** | SX1278 | SX1262 (Lower power, more range) |
| **Deep Sleep** | ~100µA (Hardware dependent) | ~10µA - 50µA (S3 optimized) |
| **USB Connector** | Micro-USB | USB Type-C |
| **Battery Connector** | JST PH 2.0mm | SH 1.25mm |
| **Dimensions (L x W)**| 51 x 23 mm | 58x22mm (Stick) / 50x25mm (V3) |

## 3. Power Management for the Pedal (Transmitter)
One of the primary concerns is maintaining the long battery life of the pedal. The ESP32-S3 can achieve comparable or better performance through the following strategies:

*   **Modular Shutdown:** WiFi and Bluetooth can be explicitly turned off via software (`WiFi.mode(WIFI_OFF)` and `btStop()`) when the pedal is in active manual mode.
*   **Vext Control & Sensor Power:** While the legacy 32u4 uses a standard GPIO (Pin 5) to toggle sensor power, the ESP32 **Vext** port provides professional-grade power management:
    *   **Current Capacity:** Standard GPIOs are limited to ~20-40mA, which can be insufficient for peak ToF sensor demands. Vext is backed by a MOSFET and can handle 300-500mA, ensuring stable operation.
    *   **Hardware Isolation:** Vext physically disconnects the power rail, preventing parasitic current leakage that can occur through data lines (SDA/SCL) in GPIO-based setups during sleep.
    *   **Signal Stability:** The Vext rail provides cleaner power than a CPU I/O pin, reducing optical noise in precision measurements.
*   **Modern Deep Sleep:** The ESP32-S3 RTC (Real-Time Clock) allows for instant wake-up from GPIO interrupts (pedal movement) with extremely low current draw.

## 4. Radio Evolution: SX1278 vs. SX1262
While both chips are compatible at the protocol level (433MHz), the **SX1262** included in most ESP32 V3 boards offers:
*   **Reduced RX Current:** Uses approx. 40% less power during reception.
*   **Higher Link Budget:** Slightly better range and obstacle penetration.
*   **Better Safety:** Improved handling of transmission failures.

## 5. Recommended Hardware Models
To ensure full compatibility and use of the features described above, the following models are specified:
*   **Transmitter (Pedal):** **Heltec Wireless Stick Lite V3 (SX1262)**. Chosen for its slim form factor, low power consumption (No OLED), and integrated Vext control.
*   **Receiver:** **Heltec WiFi LoRa 32 V3 (SX1262)**. Chosen for its integrated OLED display, S3 processing power, and full WiFi/BLE gateway capabilities.

## 6. Implementation Notes
*   **Vext Control (Stick Lite V3):** The Vext power rail on the Wireless Stick Lite V3 is controlled via **GPIO 36**. 
    *   `digitalWrite(36, LOW)` enables power to the sensor.
    *   `digitalWrite(36, HIGH)` physically cuts power for ultra-low consumption.
*   **Pins:** Pin mapping will change; the ESP32 has many more GPIOs but requires careful selection of "strapping pins."
*   **Battery Connector Change (CRITICAL):** 
    *   **Legacy (LoRa32u4):** Uses a **JST PH 2.0mm** (2.0mm pitch).
    *   **New (ESP32 V3):** Uses a **SH 1.25mm** (1.25mm pitch).
    *   **Warning:** Most Heltec boards use a specific polarity (looking at the connector with pins facing you, Red/+ is typically on the right, but this varies by clone). **Always use a multimeter** to verify the board's polarity before plugging in a battery to avoid blowing the charging IC.
*   **Libraries:** Transition from `LoRa.h` to more modern libraries like `RadioLib` or the Heltec-specific libraries is recommended for full SX1262 support.
*   **Logic:** The core safety logic (Failsafes, Median Filters) will be ported as a new "Core" library shared between both units.

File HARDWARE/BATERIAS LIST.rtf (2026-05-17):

Modelo | Capacidad Aprox. | Grosor | Ancho | Largo | Ideal para...
103450 | 1800 - 2000 mAh | 10.0 mm | 34 mm | 50 mm | Cajas de tamaño medio donde se puede apurar el grosor al máximo permitido para duplicar la capacidad estándar.
805060 | 2500 mAh | 8.0 mm | 50 mm | 60 mm | Nodos LoRa o estaciones meteorológicas planas con carcasas un poco más anchas impresas en 3D.
905060 | 3000 mAh | 9.0 mm | 50 mm | 60 mm | Igual que la anterior, pero apurando 1 mm más de grosor para rascar 500 mAh extra de autonomía.
105568 | 4000 mAh | 10.0 mm | 55 mm | 68 mm | Proyectos de alto consumo desatendidos durante meses (ej. lectura continua de sensores láser o envío muy frecuente de datos).
60 mm

906090 | 5000 - 6000 mAh | 9.0 mm

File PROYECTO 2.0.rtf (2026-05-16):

Antigravity

@Stitch, inicia un proyecto web para Wordpress (last version) con ecommerce (woocoomerce), el cual subire a un servidor (hostalia). Los archivos del Theme y Pluguins a crear tienen que estar dentro de la carpeta raiz “wireless-pedal/wp-content/“, una carperta independiente SQL (del wordpress). Proyecto: Web de venta y desarrollo de un pedal de soldadora inalámbrico (radio frecuencia 433mhz), Open Sourse (arduino) e impresion 3D (materiales opcionales). Diseño: front end de una sola pagina vertical. Secciones: 0- cabecera con imagen del pedal y un pequeño texto explicativo, 1- video en loop width 100% heigh 20%, 2- explicación mas detallada de tecnología utilizada y alcance de la integración en otras soldadoras (colección de 5 pins, Welding Trigger y Potentiometer), sección de descarga de los archivos DIY mediante pago “precio 5eurs” (ventana pop-up de pago PayPal), 3- comunidad foro y GitHub links. Requisitos: imágenes del producto deben ser ficticias hasta que reemplace por las originales.

CAMBIOS:

MODULOS 433Mhx - LoRa32u4
Remplazo de relay por: Mosfet aislado LR7843
agregar pantalla OLED de 0.91" (128x32 píxeles) al receptor para ver:
• niveles de Materia emisor y receptor
• Coneccion y desconeccion, datos de potenciometro 0 - 100%

Conclusión y Recomendación
Para un botón lineal tipo potenciómetro en una placa LoRa32u4:
1. Elige el VL53L4CD si buscas la mejor experiencia de usuario. Es el más lineal y el que menos zona muerta tiene, lo que hará que el movimiento del botón se sienta natural y profesional sin saltos en los datos.
2. Elige el VL6180X si quieres algo económico, fácil de programar y con mucha documentación disponible. Es un "todoterreno" para distancias de menos de 10 cm.
Mi consejo final: Dado que vas a usar una placa con radio LoRa (que consume mucho al transmitir), asegúrate de usar el pin XSHUT (en el VL53L4CD) o SHDN (en el VL6180X) conectado a un pin digital de tu Arduino. De esta forma, puedes apagar el sensor por completo mientras la placa está en "deep sleep" y despertar ambos solo cuando necesites tomar una lectura.

**** 1 Seguridad: Es vital tener la antena de 433MHz conectada antes de encender las placas para no dañar los módulos.

📄 OPEN SOURCE PROJECT: Wireless Industrial Pedal for Welding Machines (TIG/MIG)
Version: 1.0 (Stable Edition with Fail Safe, Auto-Rescue, and Ground Isolation)
Hardware Base: RF-NANO (Arduino Nano + Integrated nRF24L01)

1. THE TRANSMITTER (Pedal Side)
The transmitter reads the physical position of the pedal and wirelessly transmits this information to the receiver. All auxiliary switches have been removed; the entire system is controlled seamlessly via the main potentiometer.
1.1 Hardware List (Transmitter)
• MODULOS 433Mhx - LoRa32u4
• Sensor láser de proximidad VL53L4CD
• Limit-Switch
• cables
• Pedal 3D printed parts
LORA32U4-SX1278-433, VL53L4CDV0DH/1, LIPO-103048-1500, LIMIT-SWITCH-KW12, AWG22-SINGLE-CORE

1.3 Transmitter Code (C++)
C++

#include <SPI.h>

#include <nRF24L01.h>

#include <RF24.h>

RF24 radio(10, 9);
const byte direccion[6] = "PEDAL";

// Data Structure (Switches removed, only Potentiometer)
struct DatosPedal {
int valorPot;
};

DatosPedal miPedal;

void setup() {
Serial.begin(9600);
Serial.println(F("--- PEDAL TRANSMITTER V5.0 ---"));

if (!radio.begin()) {
Serial.println(F("Error: Radio hardware not detected"));
while (1);
}

radio.openWritingPipe(direccion);
radio.setPALevel(RF24_PA_LOW); // Enhances power stability
radio.setDataRate(RF24_250KBPS);
radio.stopListening();
}

void loop() {
// Read Potentiometer value
miPedal.valorPot = analogRead(A0);

// Send data
bool ok = radio.write(&miPedal, sizeof(DatosPedal));
imprimirActividad(ok);

delay(50);
}

void imprimirActividad(bool exito) {
static unsigned long lastPrint = 0;
if (millis() - lastPrint > 250) {
Serial.print(F("POT: ")); Serial.print(miPedal.valorPot);
Serial.println(exito ? F(" | STATUS: OK") : F(" | STATUS: ERROR"));
lastPrint = millis();
}
}

2. THE RECEIVER (Welder Side)
The receiver converts the wireless signal into a real analog voltage (0-10V) for amperage control. It uses two electromechanical relays: one to start the welding arc, and another to isolate the welder's potentiometer ground when resting, eliminating any signal noise.
• MODULOS 433Mhx - LoRa32u4
• Conector GX12 / male
• 2x Mosfet LR7843-30V
• OLED 128X32 pantalla
• Convertidor PWM a DAC 0-5V / 0-10V (para 10-12v)

2.3 Receiver Code (V5.0 Final)
C++

#include <SPI.h>

#include <nRF24L01.h>

#include <RF24.h>

RF24 radio(10, 9);
const byte direccion[6] = "PEDAL";

struct DatosPedal {
int valorPot;
};

DatosPedal miPedal;

// CALIBRATION VARIABLES
int PotMin = 80;
int PotMax = 1000;
unsigned long recoveryDelay = 800; // 0.8 seconds critical threshold

unsigned long ultimaRecepcion = 0;
bool sistemaBloqueado = true;
String statusActual = "INITIALIZING";

void setup() {
Serial.begin(9600);
Serial.println(F("--- WELDER RECEIVER V5.0 ---"));

radio.begin();
radio.openReadingPipe(1, direccion);
radio.setPALevel(RF24_PA_LOW);
radio.setDataRate(RF24_250KBPS);
radio.startListening();

pinMode(3, OUTPUT); // PWM Output (0-10V)
pinMode(4, OUTPUT); // RELAY 1: Torch Trigger
pinMode(5, OUTPUT); // RELAY 2: Potentiometer GND Isolation

activarFailsafe();
}

void loop() {
// Radio Auto-Rescue (SPI Bus protection)
if (radio.failureDetected) {
radio.begin();
radio.openReadingPipe(1, direccion);
radio.setPALevel(RF24_PA_LOW);
radio.setDataRate(RF24_250KBPS);
radio.startListening();
radio.failureDetected = false;
}

// 1. DATA RECEPTION
if (radio.available()) {
radio.read(&miPedal, sizeof(DatosPedal));
ultimaRecepcion = millis();
sistemaBloqueado = false;
statusActual = "CONNECTED";

int valorLimpio = constrain(miPedal.valorPot, PotMin, PotMax);
int salidaPWM;

// Absolute cut-off at rest position
if (miPedal.valorPot <= (PotMin + 10)) {
salidaPWM = 0;
digitalWrite(3, LOW);
} else {
salidaPWM = map(valorLimpio, PotMin, PotMax, 0, 255);
analogWrite(3, salidaPWM);
}

// Double Relay Activation (Torch & Ground Isolation)
bool estadoTrigger = (miPedal.valorPot > (PotMin + 25)) ? HIGH : LOW;
digitalWrite(4, estadoTrigger); // Fire Torch
digitalWrite(5, estadoTrigger); // Connect Ground
}

// 2. STATUS & SECURITY MANAGEMENT (FAIL SAFE)
unsigned long tiempoSinDatos = millis() - ultimaRecepcion;

if (!sistemaBloqueado) {
if (tiempoSinDatos > 100 && tiempoSinDatos < recoveryDelay) {
statusActual = "LOST SIGNAL";
}
else if (tiempoSinDatos >= recoveryDelay) {
activarFailsafe();
sistemaBloqueado = true;
statusActual = "FAIL SAFE - WELDER OFF";
}
}

imprimirTodo();
}

void activarFailsafe() {
digitalWrite(3, LOW);
digitalWrite(4, LOW);
digitalWrite(5, LOW);
}

void imprimirTodo() {
static unsigned long lp = 0;
if (millis() - lp > 200) {
int porcentaje = 0;
if (statusActual != "FAIL SAFE - WELDER OFF") {
porcentaje = map(constrain(miPedal.valorPot, PotMin, PotMax), PotMin, PotMax, 0, 100);
}

Serial.print(F("POT: ")); Serial.print(miPedal.valorPot);
Serial.print(F(" | %: ")); Serial.print(porcentaje);
Serial.print(F(" | RELAYS: ")); Serial.print(digitalRead(4) ? F("ON") : F("OFF"));
Serial.print(F(" | STATUS: ")); Serial.println(statusActual);

lp = millis();
}
}

3. FINAL INSTALLATION NOTES
1. Thermal & Electrical Isolation: The receiver must be installed in a non-conductive enclosure to protect it from metal dust, heat, and direct high-frequency arcs inside the welding machine.
2. Relay Advantage: The use of mechanical HJR-4102-L-5V relays ensures absolute zero leakage current when the pedal is not pressed. Relay 2 strictly disconnects the potentiometer ground, completely neutralizing any phantom voltages or electrical noise that could confuse the welder's logic board at 0% throttle.
3. Fail Safe System: If the pedal runs out of battery, goes out of range, or suffers from severe electromagnetic interference, the receiver will automatically trigger the Fail Safe protocol in under 0.8 seconds, shutting down the relays and stopping the welding arc immediately.

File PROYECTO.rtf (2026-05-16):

Aliexpress Afiliados:
I am an electronics developer creating an open-source wireless pedal project. I have a Bill of Materials (BOM) page on my website where users can buy the exact components to replicate my project. My traffic comes from the maker and DIY electronics community.

Transmitter hardware:
• MODULOS 433Mhx - LoRa32u4: DIYmall 2 Sets LoRa32u4 RA-02 Placa de Desarrollo de 433MHz con Antena, Chip SX1278 de Largo Alcance de 1KM para Proyectos IoT (http://es.aliexpress.com/item/1005010740065797.html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)
• LCD
• Batería de Polímero de Litio Recargable de 3.7V 103048 1500mAh, Batería de Repuesto para Faros Delanteros, Lámparas de Camping, Masajeadores de Audio (http://es.aliexpress.com/item/1005011524169071.html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)
• Sensor de Distancia ToF de Alta Precisión VL53L4CD, Sensor de Proximidad de 1 mm a 1300 mm para Arduino ESP32 (http://es.aliexpress.com/item/1005011974180379.html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)
• Resortes de torsión de acero inoxidable 304, 5 uds., tipo V, 1,0mm de diámetro de alambre, 6 vueltas, resorte de reinicio personalizado de Metal de 60 grados (http://es.aliexpress.com/item/1005010455807983.html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)
• Conectores GX12, MALE (al pedal) 5 pines, 6 pines, M12 (http://es.aliexpress.com/item/1005006162408269.html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)
• limit switch 3a250vac ms-105 (http://es.aliexpress.com/item/32812520453.html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)

Receiver Hardware:

• MODULOS 433Mhx - LoRa32u4: DIYmall 2 Sets LoRa32u4 RA-02 Placa de Desarrollo de 433MHz con Antena, Chip SX1278 de Largo Alcance de 1KM para Proyectos IoT (http://es.aliexpress.com/item/1005010740065797.html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)
• Módulo de pantalla OLED de 0,91 pulgadas blanco/azul OLED 128X32 pantalla LED LCD SSD1306 12832 0,91 IIC i2C comunicación para ardunio (http://es.aliexpress.com/item/1005008640108394.html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)
• Módulo de alimentación MOSFET aislado (alternativa de relé): (https://es.aliexpress.com/item/1005010491208213.html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)
• Convertidor PWM a DAC entrada salida de señal de pulso 0-5V/0-10V voltaje analógico para Arduiuo MEGA2560 PLC Raspberr Pi ESP32 NodeMCU (http://es.aliexpress.com/item/1005006246628087.html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)
• Batería de Polímero de Litio Recargable de 3.7V 103048 1500mAh, Batería de Repuesto para Faros Delanteros, Lámparas de Camping, Masajeadores de Audio (http://es.aliexpress.com/item/1005011524169071.html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)

📄 OPEN SOURCE PROJECT: Wireless Industrial Pedal for Welding Machines (TIG/MIG)
Version: 1.0 (Stable Edition with Fail Safe, Auto-Rescue, and Ground Isolation)
Hardware Base: RF-NANO (Arduino Nano + Integrated nRF24L01)

1. THE TRANSMITTER (Pedal Side)
The transmitter reads the physical position of the pedal and wirelessly transmits this information to the receiver. All auxiliary switches have been removed; the entire system is controlled seamlessly via the main potentiometer.
1.1 Hardware List (Transmitter)
Qty | Component | Function
1 | RF-NANO | Microcontroller & Radio Transmitter.
1 | 10k Linear Potentiometer | Pedal position sensor.
1 | Isolated AC-DC Switching Power Supply (5V DC) | Mini Step-Down Buck Converter (Input 90-265V AC to Output 5V DC). Provides highly stable and isolated power.
1 | 100µF Capacitor | Critical stability filter for the radio module.
1.2 Connection Scheme (Transmitter)
• Power Supply: Connect the 5V DC output from the Isolated AC-DC module directly to the 5V and GND pins of the RF-NANO.
• Capacitor: Solder the 100µF capacitor in parallel between the 5V and GND pins.
• Potentiometer: * Pin 1 (Left) $\rightarrow$ GND.
◦ Pin 2 (Center/Wiper) $\rightarrow$ A0.
◦ Pin 3 (Right) $\rightarrow$ 5V.
Plaintext

[ AC-DC 5V ISOLATED POWER SUPPLY ]
(+) (-)
v v
(5V) (GND)
+-----------------------------+
| RF-NANO |
| (A0) |
+--|--------------------------+
v
[ 10K POTENTIOMETER ]
(GND) (Center) (5V)
^ ^ ^
+------+------+--- (Powered from RF-NANO 5V/GND)
1.3 Transmitter Code (C++)
C++

#include <SPI.h>

#include <nRF24L01.h>

#include <RF24.h>

RF24 radio(10, 9);
const byte direccion[6] = "PEDAL";

// Data Structure (Switches removed, only Potentiometer)
struct DatosPedal {
int valorPot;
};

DatosPedal miPedal;

void setup() {
Serial.begin(9600);
Serial.println(F("--- PEDAL TRANSMITTER V5.0 ---"));

if (!radio.begin()) {
Serial.println(F("Error: Radio hardware not detected"));
while (1);
}

radio.openWritingPipe(direccion);
radio.setPALevel(RF24_PA_LOW); // Enhances power stability
radio.setDataRate(RF24_250KBPS);
radio.stopListening();
}

void loop() {
// Read Potentiometer value
miPedal.valorPot = analogRead(A0);

// Send data
bool ok = radio.write(&miPedal, sizeof(DatosPedal));
imprimirActividad(ok);

delay(50);
}

void imprimirActividad(bool exito) {
static unsigned long lastPrint = 0;
if (millis() - lastPrint > 250) {
Serial.print(F("POT: ")); Serial.print(miPedal.valorPot);
Serial.println(exito ? F(" | STATUS: OK") : F(" | STATUS: ERROR"));
lastPrint = millis();
}
}

2. THE RECEIVER (Welder Side)
The receiver converts the wireless signal into a real analog voltage (0-10V) for amperage control. It uses two electromechanical relays: one to start the welding arc, and another to isolate the welder's potentiometer ground when resting, eliminating any signal noise.
2.1 Hardware List (Receiver)
Qty | Component | Function
1 | RF-NANO | Microcontroller & Radio Receiver.
1 | PWM to 0-10V Module | Converts the D3 digital signal into analog voltage.
2 | 5V Relay Modules (HJR-4102-L-5V) | Dry contacts for Torch Trigger and Ground Isolation.
1 | Isolated AC-DC Switching Power Supply (5V DC) | Mini Step-Down Buck Converter (Input 90-265V AC to Output 5V DC).
1 | 100µF Capacitor | Critical filter against High Frequency (HF) arc noise.
2.2 Connection Scheme (Receiver)
IMPORTANT POWER NOTICE: The RF-NANO and Relay modules are powered by the 5V Isolated AC-DC supply. However, the PWM to 0-10V Module typically requires an external 12V-24V power source (usually sourced directly from the welder's internal mainboard) to successfully generate a 10V output.
• Main Power: Connect the 5V Isolated supply to the 5V and GND pins of the RF-NANO.
• Filter: Solder the 100µF capacitor between 5V and GND.
• PWM Signal (Amperage): Pin D3 connects to the PWM input of the 0-10V converter module.
• Relay 1 (Torch Trigger): Pin D4 controls this relay. The relay's Common (COM) and Normally Open (NO) pins connect to the welder's trigger wires.
• Relay 2 (GND Isolation): Pin D5 controls this relay. This relay physically disconnects the ground (GND) of the welder's amperage control when the pedal is at rest. This completely eliminates low-end electrical noise.
Plaintext

[ AC-DC 5V ISOLATED POWER SUPPLY ]
(+) (-)
v v
(5V) (GND)
+-----------------------------+
| RF-NANO |
| (D3) (D4) (D5) |
+--|----------|----------|----+
v v v
[PWM MODULE] [RELAY 1] [RELAY 2]
(0-10V) (TORCH) (POT GND)
2.3 Receiver Code (V5.0 Final)
C++

#include <SPI.h>

#include <nRF24L01.h>

#include <RF24.h>

RF24 radio(10, 9);
const byte direccion[6] = "PEDAL";

struct DatosPedal {
int valorPot;
};

DatosPedal miPedal;

// CALIBRATION VARIABLES
int PotMin = 80;
int PotMax = 1000;
unsigned long recoveryDelay = 800; // 0.8 seconds critical threshold

unsigned long ultimaRecepcion = 0;
bool sistemaBloqueado = true;
String statusActual = "INITIALIZING";

void setup() {
Serial.begin(9600);
Serial.println(F("--- WELDER RECEIVER V5.0 ---"));

radio.begin();
radio.openReadingPipe(1, direccion);
radio.setPALevel(RF24_PA_LOW);
radio.setDataRate(RF24_250KBPS);
radio.startListening();

pinMode(3, OUTPUT); // PWM Output (0-10V)
pinMode(4, OUTPUT); // RELAY 1: Torch Trigger
pinMode(5, OUTPUT); // RELAY 2: Potentiometer GND Isolation

activarFailsafe();
}

void loop() {
// Radio Auto-Rescue (SPI Bus protection)
if (radio.failureDetected) {
radio.begin();
radio.openReadingPipe(1, direccion);
radio.setPALevel(RF24_PA_LOW);
radio.setDataRate(RF24_250KBPS);
radio.startListening();
radio.failureDetected = false;
}

// 1. DATA RECEPTION
if (radio.available()) {
radio.read(&miPedal, sizeof(DatosPedal));
ultimaRecepcion = millis();
sistemaBloqueado = false;
statusActual = "CONNECTED";

int valorLimpio = constrain(miPedal.valorPot, PotMin, PotMax);
int salidaPWM;

// Absolute cut-off at rest position
if (miPedal.valorPot <= (PotMin + 10)) {
salidaPWM = 0;
digitalWrite(3, LOW);
} else {
salidaPWM = map(valorLimpio, PotMin, PotMax, 0, 255);
analogWrite(3, salidaPWM);
}

// Double Relay Activation (Torch & Ground Isolation)
bool estadoTrigger = (miPedal.valorPot > (PotMin + 25)) ? HIGH : LOW;
digitalWrite(4, estadoTrigger); // Fire Torch
digitalWrite(5, estadoTrigger); // Connect Ground
}

// 2. STATUS & SECURITY MANAGEMENT (FAIL SAFE)
unsigned long tiempoSinDatos = millis() - ultimaRecepcion;

if (!sistemaBloqueado) {
if (tiempoSinDatos > 100 && tiempoSinDatos < recoveryDelay) {
statusActual = "LOST SIGNAL";
}
else if (tiempoSinDatos >= recoveryDelay) {
activarFailsafe();
sistemaBloqueado = true;
statusActual = "FAIL SAFE - WELDER OFF";
}
}

imprimirTodo();
}

void activarFailsafe() {
digitalWrite(3, LOW);
digitalWrite(4, LOW);
digitalWrite(5, LOW);
}

void imprimirTodo() {
static unsigned long lp = 0;
if (millis() - lp > 200) {
int porcentaje = 0;
if (statusActual != "FAIL SAFE - WELDER OFF") {
porcentaje = map(constrain(miPedal.valorPot, PotMin, PotMax), PotMin, PotMax, 0, 100);
}

Serial.print(F("POT: ")); Serial.print(miPedal.valorPot);
Serial.print(F(" | %: ")); Serial.print(porcentaje);
Serial.print(F(" | RELAYS: ")); Serial.print(digitalRead(4) ? F("ON") : F("OFF"));
Serial.print(F(" | STATUS: ")); Serial.println(statusActual);

lp = millis();
}
}

3. FINAL INSTALLATION NOTES
1. Thermal & Electrical Isolation: The receiver must be installed in a non-conductive enclosure to protect it from metal dust, heat, and direct high-frequency arcs inside the welding machine.
2. Relay Advantage: The use of mechanical HJR-4102-L-5V relays ensures absolute zero leakage current when the pedal is not pressed. Relay 2 strictly disconnects the potentiometer ground, completely neutralizing any phantom voltages or electrical noise that could confuse the welder's logic board at 0% throttle.
3. Fail Safe System: If the pedal runs out of battery, goes out of range, or suffers from severe electromagnetic interference, the receiver will automatically trigger the Fail Safe protocol in under 0.8 seconds, shutting down the relays and stopping the welding arc immediately.

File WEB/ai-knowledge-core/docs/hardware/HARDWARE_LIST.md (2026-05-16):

# HARDWARE COMPONENTS LIST (Sync from CSV)

This document is automatically generated from `HARDWARE_LIST_CLASSIFIED.csv`.

## 📦 GENERAL

| Component | Name | Specifications | Category |
| :--- | :--- | :--- | :--- |

---

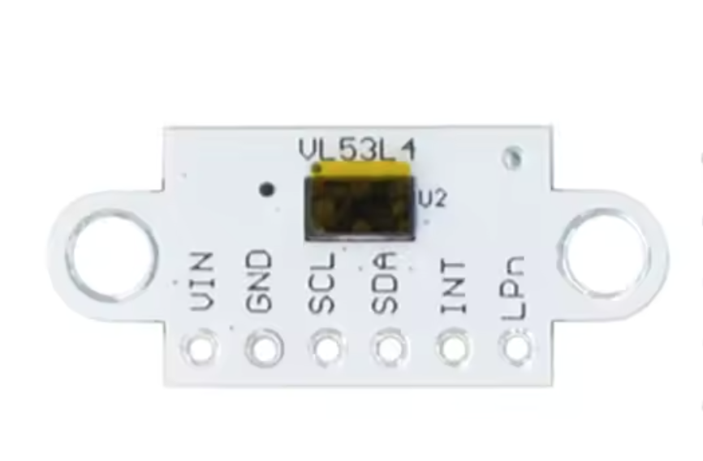
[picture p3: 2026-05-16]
HARDWARE/ToF VL53L4CD.png

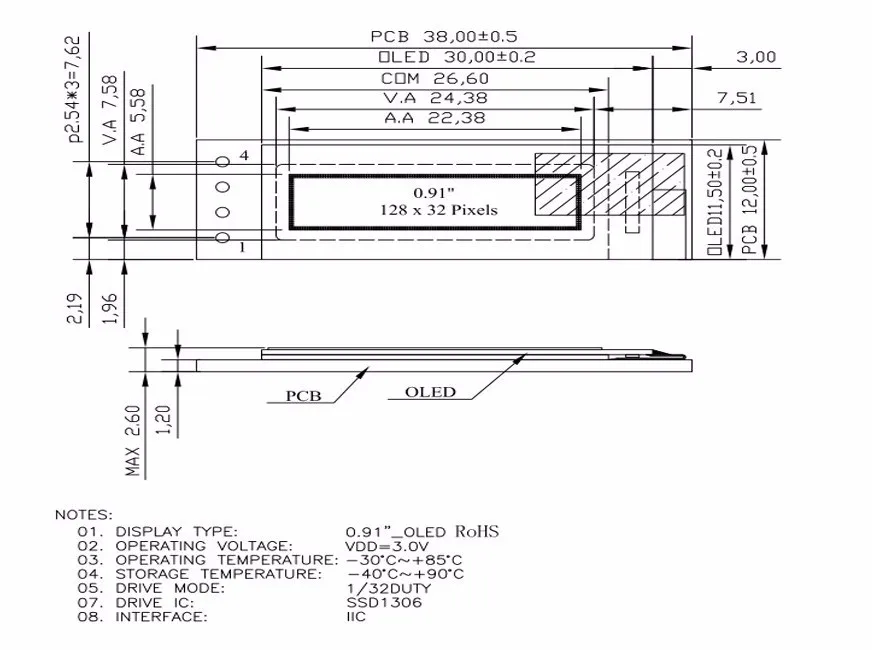
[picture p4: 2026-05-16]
HARDWARE/LoRa32u4 RA-02 433MH-2.webp

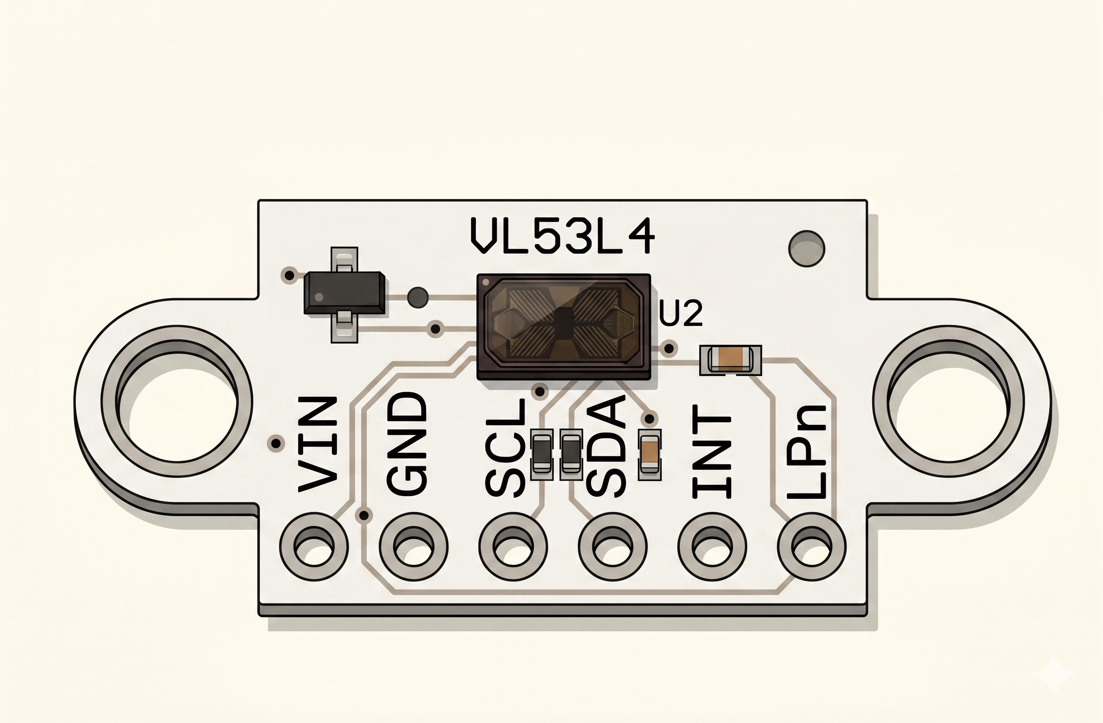
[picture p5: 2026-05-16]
HARDWARE/ToF VL53L4CD - Flat 2D Vector Illustration.png

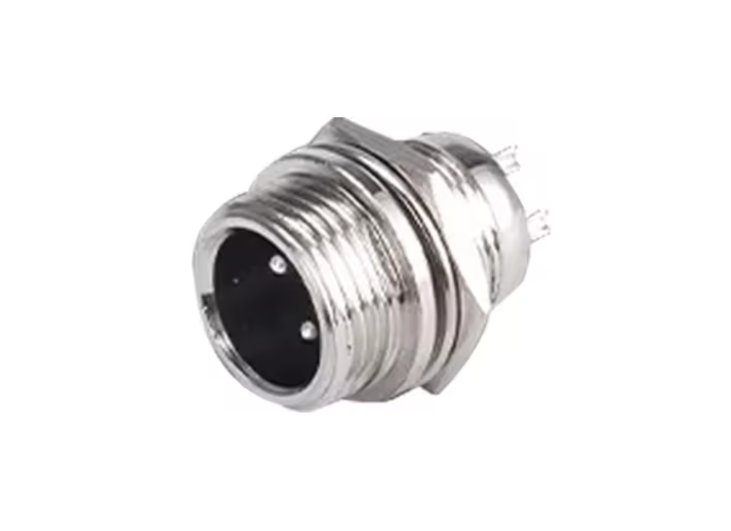
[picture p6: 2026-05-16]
HARDWARE/GX12-5PIN-M - 1.png

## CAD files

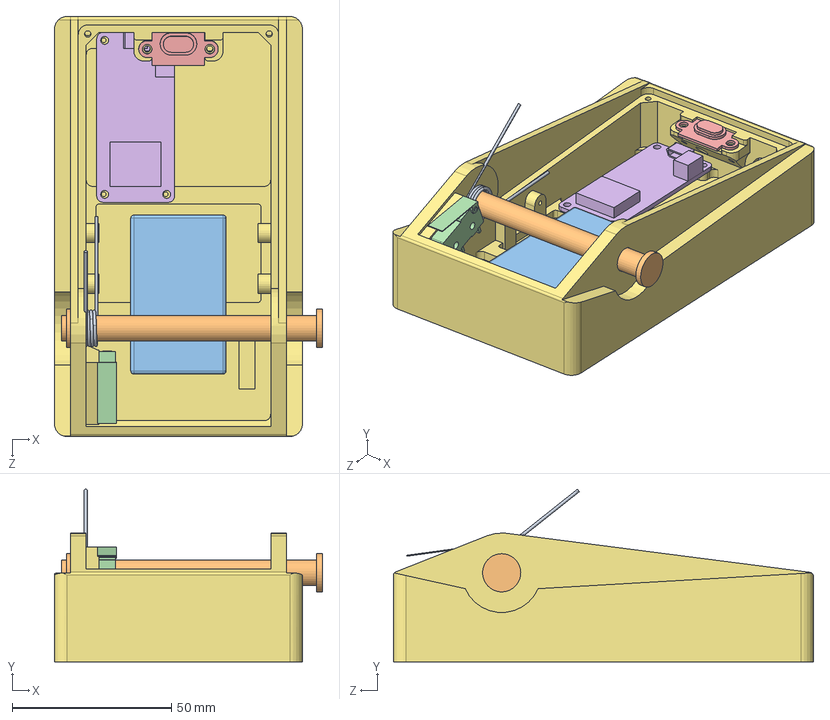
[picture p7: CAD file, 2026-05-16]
DRAWINGS/WELDING-PEDAL-COMPLETE.SLDASM
84.3 x 54.3 x 132.0 mm
BASE
LoRa 32u4
Sensor ToF
limit switch
battery-lipo-103048
AXLE
SPRING

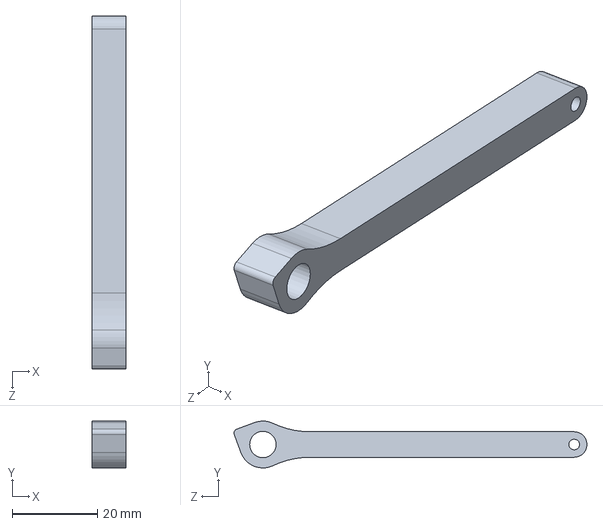
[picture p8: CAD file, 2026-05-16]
DRAWINGS/CRANK.SLDPRT
8.00 x 11.0 x 82.8 mm

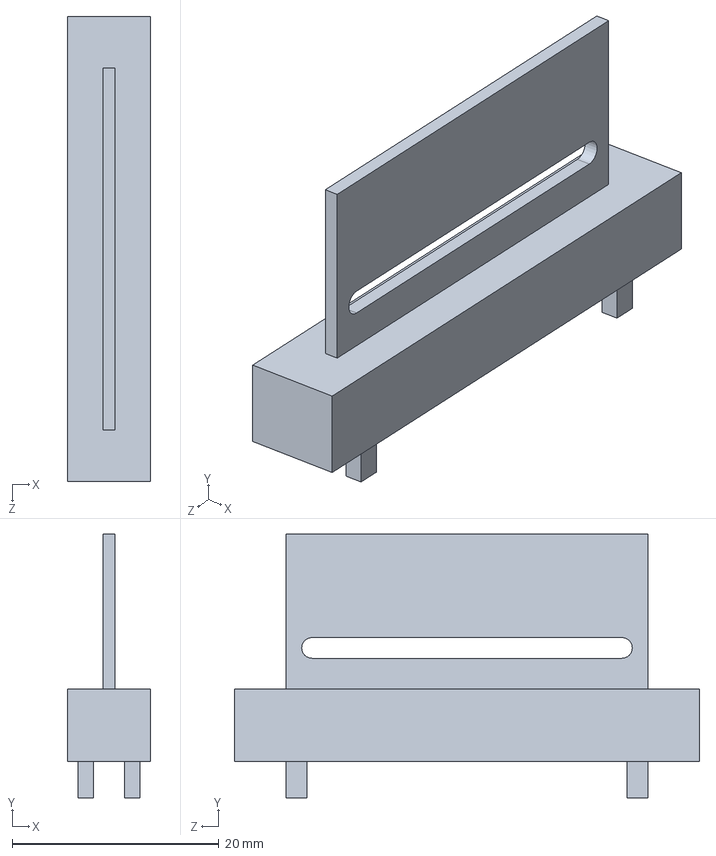
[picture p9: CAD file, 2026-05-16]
DRAWINGS/POTENTIOMETER.SLDPRT
8.00 x 25.5 x 45.0 mm

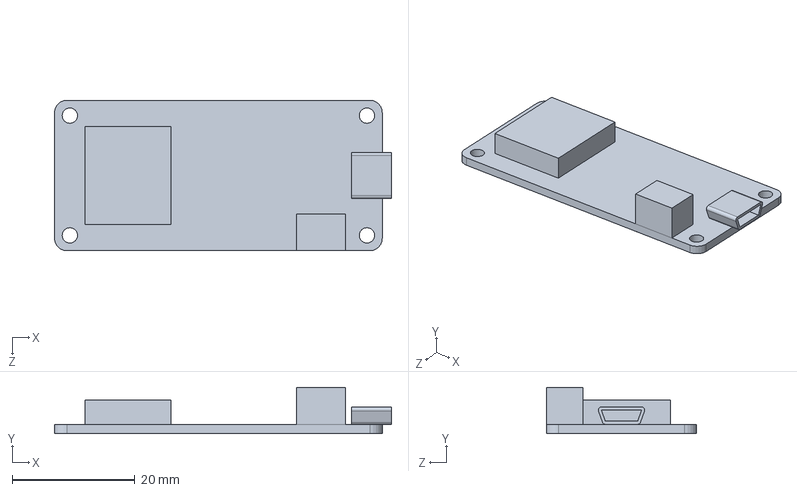
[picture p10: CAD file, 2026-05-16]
DRAWINGS/LoRa 32u4.SLDPRT
54.9 x 7.50 x 24.5 mm

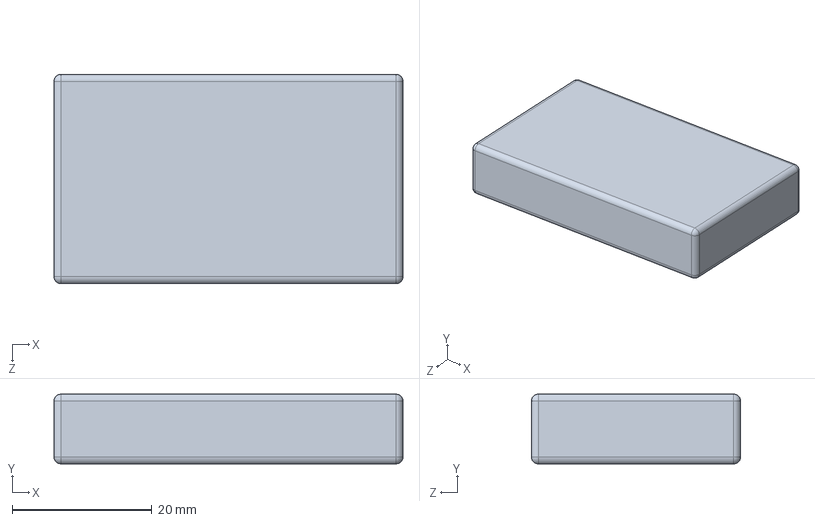
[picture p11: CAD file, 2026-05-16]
DRAWINGS/battery-lipo-103048.SLDPRT
50.0 x 10.0 x 30.0 mm

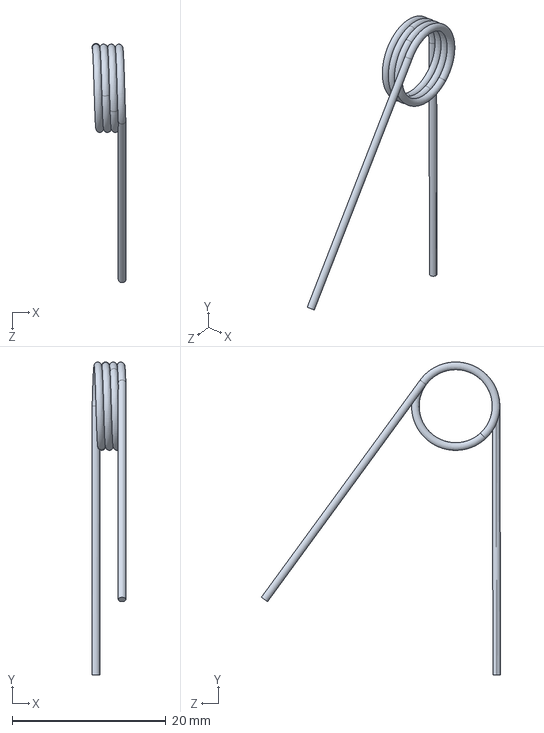
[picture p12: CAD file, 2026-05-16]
DRAWINGS/SPRING.SLDPRT
4.40 x 40.7 x 31.1 mm

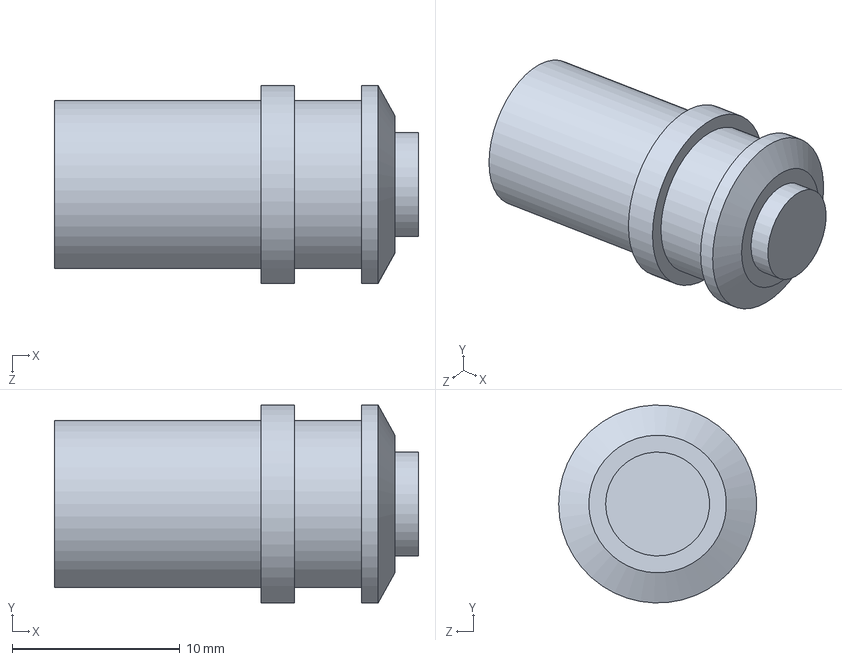
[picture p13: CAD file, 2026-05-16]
DRAWINGS/SWITCH-ON.SLDPRT
21.7 x 11.8 x 11.8 mm

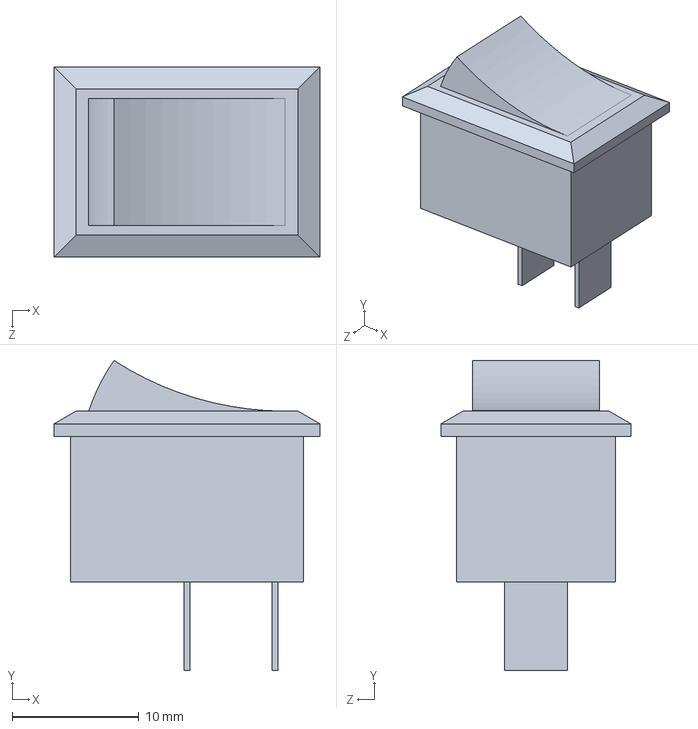
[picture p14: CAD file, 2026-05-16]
DRAWINGS/SWITCH.SLDPRT
21.0 x 24.5 x 15.0 mm

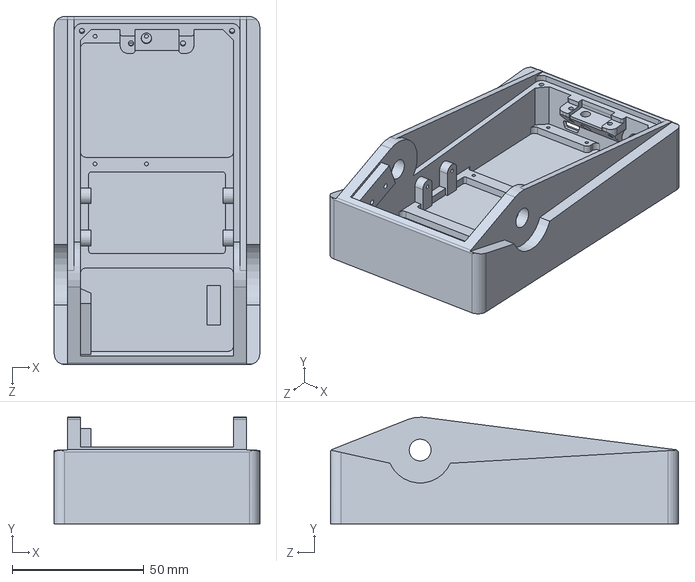
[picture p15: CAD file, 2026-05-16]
DRAWINGS/BASE.SLDPRT
78.0 x 40.5 x 132.0 mm

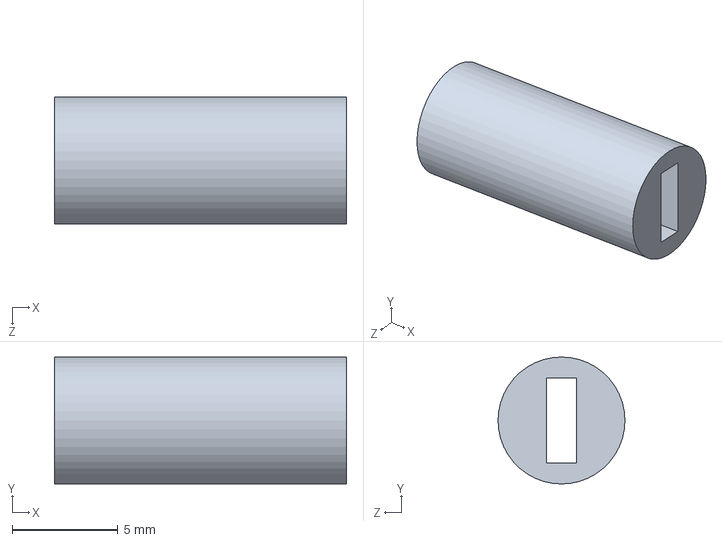
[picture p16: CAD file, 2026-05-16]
DRAWINGS/POTENTIOMETER-BUSHING.SLDPRT
13.8 x 6.00 x 6.00 mm

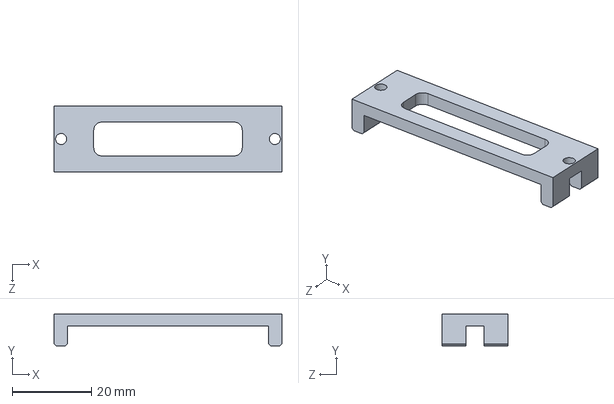
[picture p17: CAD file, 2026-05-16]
DRAWINGS/BETTERY-LOCK.SLDPRT
57.4 x 8.00 x 16.5 mm

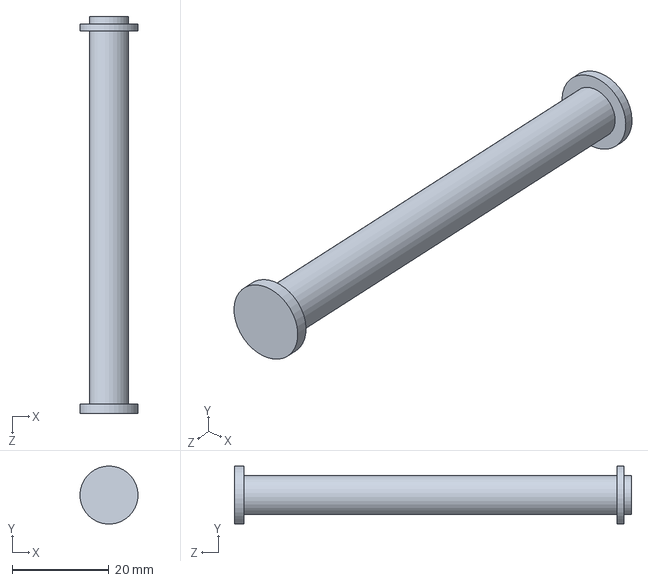
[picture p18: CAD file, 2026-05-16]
DRAWINGS/AXLE.SLDPRT
12.0 x 12.0 x 82.0 mm

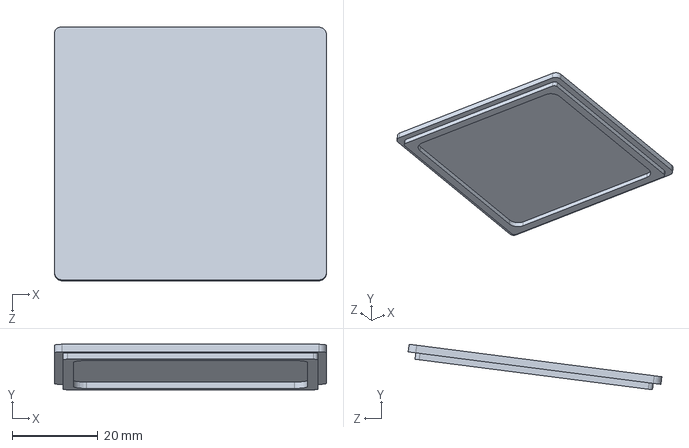
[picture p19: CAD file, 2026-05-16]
DRAWINGS/BASE-COVER.SLDPRT
63.6 x 10.6 x 59.3 mm

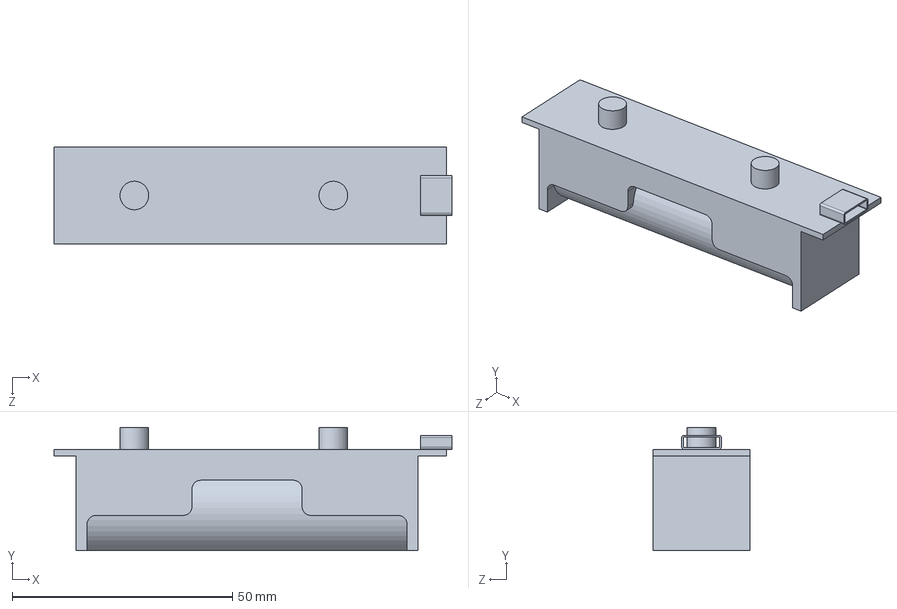
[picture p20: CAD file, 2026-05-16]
DRAWINGS/BATTERY.SLDPRT
90.4 x 28.0 x 22.0 mm

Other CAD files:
DRAWINGS/PEDAL.SLDPRT
DRAWINGS/Sensor ToF.SLDPRT
DRAWINGS/limit switch.SLDPRT
DRAWINGS/BATT-METTER.SLDPRT

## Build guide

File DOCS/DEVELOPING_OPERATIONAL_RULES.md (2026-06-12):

# Developing Operational Rules

This document outlines the mandatory operational and development rules that the AI coding assistant and developers must strictly follow when working on the **Wireless Welder Pedal** project.

---

## 1. Code & Comment Language Policy
*   **Mandatory Language:** All code symbols (variable names, function names, classes, structs, enums) and **all comments inside source code files** (`.ino`, `.h`, `.cpp`, etc.) **MUST** be written in **English**.
*   **Aesthetic & Communication:** The developer pair-programming dialogue can be bilingual (Spanish/English) as requested by the user, but the source code itself must remain 100% clean, standardized, and professional in English.

---

## 2. Git & GitHub Update Policy
*   **Absolute Strict Restriction:** **NEVER** run any Git commands (such as `git add`, `git commit`, `git push`, etc.) or modify the repository state, whether locally or on remote platforms like GitHub, **unless the user explicitly and literally commands you to do so** (e.g., "actualiza todo en git", "push git hub", etc.).
*   **Freeze by Default:** By default, all Git operations are completely frozen. The assistant must focus solely on local file modifications in the workspace and never perform git commits, pushes, or staging unless explicitly instructed.

---

## 3. Dynamic AI Update ("CHAT IA" Protocol)
*   **Knowledge Synchronization:** When the user or assistant makes significant changes to the firmware architecture or logic, the assistant must update the context logs, system blueprint, or project documents to ensure the RAG (Retrieval-Augmented Generation) knowledge base is synchronized.
*   **State Alignment:** Any changes that alter pinouts, timers, calibration multipliers, or core states must be logged immediately so the next AI pair-programming agent is perfectly aligned.

---

## 4. Firmware Versioning & Working Target Policy
*   **Target the Latest Validated Version:** When applying modifications, refactoring, migrating pins, or implementing new features, we **MUST** always target and apply changes to the **latest validated version** of the software in the active development directories (e.g.,`receiver_v1.1.ino` in the `FIRMWARE/receiver_v1.1/` folder, and `transmitter_v1.1.ino` in `FIRMWARE/transmitter_v1.1/`).
*   **Baseline Preservation:** Older versions (e.g., legacy `v1.0` under the `receiver` and `transmitter` directories) must remain untouched as stable reference baselines unless the user explicitly requests changes to be backported.

---

## 5. Hardware & Firmware Coding Directives
To ensure maximum safety, reliability, and zero latency:
1.  **Non-Blocking Logic:** Never use `delay()` in the main loops. Use non-blocking timers (`millis()`) for state transitions, display updates, and buzzer alerts. Exceptions are allowed only during the `setup()` boot phase (e.g., USB grace period) or physical quiet-periods for the ADC.
2.  **SRAM Memory Preservation:** Every literal string printed to the Serial Monitor **MUST** be encapsulated in the `F()` macro (e.g., `Serial.println(F("Hello"))`) to prevent SRAM memory exhaustion.
3.  **Non-Blocking Diagnostics:** All telemetry and diagnostic logs in the Serial Monitor must be wrapped in `if (Serial)` check, so they execute instantly and bypass printing overhead entirely when no USB Serial Monitor is connected.
4.  **Hardware-Driven Calibration:** Battery calibration multipliers (`RX_CALIBRATION`, `TX_CALIBRATION`) should be adjusted using the live suggestions generated automatically in the Serial Monitor telemetry block.
5.  **Relay Failsafe Enforcement:** The welding output relays (`PIN_REL1`, `PIN_REL2`) and the PWM signal must be immediately de-energized/locked to `0` when a signal loss (LoRa timeout) or Standby state is detected.
6.  **Embedded C++ Standard:** Always write `.ino` firmware using clean, lightweight **Embedded C++** patterns. Avoid dynamic memory allocation (no `new`/`delete` or `std::vector`), prevent runtime heap fragmentation, prefer static or stack-allocated memory, and implement object-oriented abstractions or standard patterns only when they do not introduce memory overhead or compromise firmware execution speed.

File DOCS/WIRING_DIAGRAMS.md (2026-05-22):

# WIRING DIAGRAMS: WIRELESS WELDER PEDAL v1.0 (Integrated LoRa32u4)

> **Technical Data Source:** `HARDWARE_LIST_CLASSIFIED.csv` + `transmitter.ino` / `receiver.ino`

---

> [!CAUTION]
> **CONNECT ANTENNA BEFORE POWERING ON:** Never power or turn on the LoRa32u4 board without the antenna connected. Operating the system without a load (antenna) can permanently damage the SX1278 radio chip due to power reflection.

> [!WARNING]
> **BATTERY POLARITY REVERSED:** The stock 103048 LiPo batteries usually come with the JST connector wires inverted relative to this specific board. You **MUST** swap the pins on the battery connector before plugging it in. On the LoRa32u4 controller, the **positive (+)** pin is on the **LEFT**, and the **negative (-)** pin is on the **RIGHT** (when looking at the connector from the edge of the board). Failure to do this will cause a reverse-polarity short!

---

## 1. TRANSMITTER (Pedal)

The transmitter integrates the MCU (ATmega32u4 @ 8MHz) and the LoRa SX1278 radio on a single PCB. The **MS-105 limit switch (SPDT)** activates the system: when pressed, it turns on the VL53L4CD laser sensor via XSHUT and enables the transmission of full telemetry to the receiver. The 103048 LiPo (3.7V) powers everything from the board's integrated JST connector.

### Wiring Diagram - Transmitter v7.0
Transmitter Wiring Diagram

### Visual Component Reference
Component Reference - LoRa32u4
Component Reference - Peripherals

### Connection Table - Transmitter

| Component | LoRa32u4 Pin | Wire Color | Function |
| :--- | :---: | :---: | :--- |
| **VL53L4CD - VIN** | 3V3 | 🔴 Red | 3.3V Power (Logic Voltage 2.6V-3.5V) |
| **VL53L4CD - GND** | GND | ⚫ Black | Ground |
| **VL53L4CD - SCL** | Pin 3 (SCL) | 🔵 Blue | I2C Clock |
| **VL53L4CD - SDA** | Pin 2 (SDA) | 🟡 Yellow | I2C Data |
| **VL53L4CD - LPN/XSHUT**| Pin 6 | 🟣 Purple | Laser Sleep/Wake Control (Open-Drain) |
| **MS-105 - COM** | Pin 11 | 🟢 Green | Trigger/Safety (INPUT_PULLUP, Active LOW) |
| **MS-105 - NO** | Pin 10 | ⚫ Black | Virtual GND (Set to LOW by MCU) |
| **LIPO-103048-1500 (+)** | JST BAT (LEFT) | 🔴 Thick Red | 3.7V Power (Check Polarity!) |
| **LIPO-103048-1500 (-)** | JST BAT (RIGHT)| ⚫ Thick Black | Ground |
| **Battery Monitor** | A0 (analog) | - | Internal voltage divider |
| **Power Button - Switch (+)**| Pin A1 | 🔴 Red | Momentary Power Button (INPUT_PULLUP, Active LOW) [Terminal A4 on Button] |
| **Power Button - Switch (-)**| Pin A5 | ⚫ Black | Virtual Ground for Switch (MCU set to LOW) [Terminal A3 on Button] |
| **Power Button - LED (+)**| Pin A3 | 🔴 Red | Software controlled Status LED (Blinks in Standby) [Terminal A1 on Button] |
| **Power Button - LED (-)**| Pin A4 | ⚫ Black | Virtual Ground for LED (MCU set to LOW) [Terminal A2 on Button] |

### Component Specifications (Transmitter)

| Component | Model / MPN | Key Specifications |
| :--- | :--- | :--- |
| **MCU + LoRa** | DIYmall LoRa32u4 RA-02 | ATmega32u4 @ 8MHz · SX1278 433MHz · up to 1KM · 3.3V logic |
| **ToF Sensor** | VL53L4CDV0DH/1 | ToF I2C · 1-1300mm · ±3% · Logic Voltage 2.6V-3.5V |
| **Limit Switch** | MS-105 (SPDT) | 3A 250VAC / 5A 125VAC · 1NO+1NC · 100,000 cycles |
| **Battery** | LiPo 103048-1500mAh | 3.7V nom. (4.2V full) · 10x30x48mm · rechargeable |
| **Return Springs** | 304 Stainless V-type | ø1.0mm · 6 turns · 60° · mechanical pedal reset |

> [!TIP]
> **XSHUT/LPN Resolution (v1.0 POWER-MASTER):** The LPN pin of the sensor is now connected to **Pin 6** using a purple wire. Previous I2C conflicts have been resolved in firmware v1.0 using an Open-Drain software configuration (input for ON, output LOW for OFF), allowing maximum power savings during deep sleep.
> **Trigger (Pin 11):** The trigger has been moved from Pin 5 to Pin 11 to avoid internal conflicts with the LoRa radio (DIO1), utilizing Pin 10 as a software-controlled virtual GND.

> [!CAUTION]
> **PIN 5 ADVISORY:** Pin 5 of the LoRa32u4 is internally connected to the DIO1 pin of the LoRa module. DO NOT use it as a general input/output to avoid communication failures.

---

## 2. RECEIVER (Welding Machine)

The receiver picks up the LoRa packet from the pedal and converts the distance into a PWM -> analog (0-10V) signal to control the welder's current. It uses two 4-pin **Photocoupler TLP222A (photorelays)**: one as a **firing relay** for the torch and another to **isolate the DAC module's GND**, ensuring a true 0.00V when the pedal is at rest.

### Wiring Diagram - Receiver (GND Isolation)
Receiver Wiring

### Connection Table - Receiver

| Component | LoRa32u4 Pin | Wire Color | Function |
| :--- | :---: | :---: | :--- |
| **SSD1306 OLED - SDA** | Pin 2 (SDA) | 🟡 Yellow | I2C Telemetry (distance, battery, status) |
| **SSD1306 OLED - SCK** | Pin 3 (SCL) | 🔵 Blue | I2C Clock |
| **SSD1306 OLED - VCC** | 3V3 | 🔴 Red | 3.3V Power (from board 3.3V regulator) |
| **SSD1306 OLED - GND** | GND | ⚫ Black | Ground |
| **MOSFET #1 - PWM (+)** | Pin A5 | 🟣 Purple | Relay 1 - Fires the welding torch |
| **MOSFET #1 - GND (-)** | Pin 10 | ⚫ Black | Virtual Control Ground (MCU set to LOW) |
| **MOSFET #2 - PWM (+)** | Pin A3 | 🟠 Orange | Relay 2 - Connects/disconnects DAC GND |
| **MOSFET #2 - GND (-)** | Pin 12 | ⚫ Black | Virtual Control Ground (MCU set to LOW) |
| **PWM-to-DAC - (PWM)** | Pin 9 | 🟡 Yellow | PWM Signal Input (from MCU) |
| **PWM-to-DAC - (GND L)** | Pin 6 | ⚫ Black | Logic Ground (MCU set to LOW) |
| **PWM-to-DAC - (VIN)** | GX12 Pin 5 | 🟡 Yellow | Power Supply (+) from Welder (10-12V) |
| **PWM-to-DAC - (GND In)** | MOSFET #2 (L) | ⚫ Black | Switched Ground (Galvanic Isolation) |
| **PWM-to-DAC - (Vo)** | GX12 Pin 7 | 🟢 Green | 0-10V Analog Output to welder |
| **LIPO-103048-1500 (+)** | JST BAT (LEFT) | 🔴 Thick Red | 3.7V Power (Check Polarity!) |
| **LIPO-103048-1500 (-)** | JST BAT (RIGHT)| ⚫ Thick Black | Ground |
| **Buzzer (Alarm)** | Pin A4 | 🟢 Green | Active Buzzer acoustic alarm |
| **GX12-5P Connector** | Male Plug | - | [See Pinout Table below] |
| **Power Button - Switch** | EN / GND | ⚫ Black | M10 Button (Latching) - Connect to EN / GND |
| **Power Button - LED (+)**| Pin A1 | 🔴 Red | Software controlled Status LED (Solid/Off) [Terminal A1 on Button] |
| **Power Button - LED (-)**| Pin A2 | ⚫ Black | Virtual Ground for LED (MCU set to LOW) [Terminal A2 on Button] |
| **Mode Button - Switch (+)**| Pin 0 (RX) | ⚪ White | Momentary Button for Menu/Modes (Internal Pullup) |
| **Mode Button - GND (-)**  | Pin 1 (TX) | ⚫ Black | Virtual Ground for Mode button (MCU set to LOW) |

### Aviation Connector Pinout (GX12-5P Male)

This connector links the Receiver unit to the welding machine's remote/pedal port. Note that while it uses a 5-pin physical layout, the pins are numbered 2, 3, 5, 6, and 7 based on the industrial standard for this specific machine.

| Pin (GX12) | Wire Color | Function | Receiver Connection |
| :---: | :---: | :--- | :--- |
| **2** | 🔴 Red | Trigger Switch (+) | **TLP222A #1 Pin 4** (Torch switch (+) · polarity not obligatory) |
| **3** | ⚫ Black | Trigger Switch (-) | **TLP222A #1 Pin 3** (Torch switch (-) · polarity not obligatory) |
| **5** | 🟡 Yellow | Remote Ref. (10-12V) | **PWM-to-DAC - (VIN)** (⚪ White in Thermal Ark) |
| **6** | 🟤 Brown | Remote GND (Min) | **TLP222A #2 Pin 4** (GND switch (+) · polarity not obligatory) |
| **7** | 🟢 Green | Remote Wiper (Sig) | **PWM-to-DAC - (Vo) (0-10V)** |

> [!IMPORTANT]
> **NO JUMPER REQUIRED FOR TLP222A:** Unlike the traditional discrete MOSFET modules, the Photocoupler TLP222A acts as a pure solid-state photorelay. Its outputs are completely isolated, dry, bidirectional contacts that don't share a common ground or power source, providing absolute galvanic isolation out-of-the-box.

### Component Specifications (Receiver)

| Component | Model / MPN | Key Specifications |
| :--- | :--- | :--- |
| **MCU + LoRa** | DIYmall LoRa32u4 RA-02 | ATmega32u4 · SX1278 433MHz · 3.3V logic · integrated LiPo charging |
| **OLED Display** | SSD1306 0.96" | 128x64px · I2C · 4 pins (VCC, GND, SCL, SDA) · 3.3V-5V |
| **Photocoupler** | TLP222A (x2) | Toshiba Photorelay · 4-pin DIP · 60V/500mA max · Solid-state switch · 2500 Vrms isolation · Link: https://es.aliexpress.com/item/1005009404744214.html |
| **DAC Converter** | PWM-to-DAC 0-10V | PWM Input · 0-5V or 0-10V Output · 12V-30V Power · Multi-turn Pot |
| **Battery** | LiPo 103048-1500mAh | 3.7V nom. · 10x30x48mm · integrated PCM |
| **Ext. Connector** | GX12-5P Male | Industrial aviation · 12mm · 5 contacts · Zinc/Nickel |

### Photocoupler Wiring Detail (TLP222A - 4-Pin DIP)

We use two independent **TLP222A** units (each is a single-channel photorelay in a 4-pin DIP package). They act as isolated, bidirectional solid-state switches.

#### Photocoupler #1: Torch Trigger (Relay Trigger - FULLY ISOLATED)
*   **Pin 1:** `LOGIC (+)` = **Pin A5** (MCU Trigger signal)
*   **Pin 2:** `GND (-)` = **Pin 10** (Virtual ground set to LOW by MCU)
*   **Pin 3:** `switch (-)` = **GX12 Pin 3 (⚫ Black)** (polarity not obligatory)
*   **Pin 4:** `switch (+)` = **GX12 Pin 2 (🔴 Red)** (polarity not obligatory)
*   *Note: When Pin A5 goes HIGH, the internal LED conducts, bridging Pin 3 and Pin 4 together to fire the torch trigger.*

#### Photocoupler #2: DAC Ground Isolation (FULLY ISOLATED)
*   **Pin 1:** `LOGIC (+)` = **Pin A3** (MCU DAC-ON signal)
*   **Pin 2:** `GND (-)` = **Pin 12** (Virtual ground set to LOW by MCU)
*   **Pin 3:** `switch (-)` = **PWM-to-DAC - (GND In)** (⚫ Black wire) (polarity not obligatory)
*   **Pin 4:** `switch (+)` = **GX12 Pin 6 (🟤 Brown)** (polarity not obligatory)
*   *Note: This switch disconnects the DAC module's ground when the pedal is at rest, ensuring a true 0.00V.*

---

### Ground Isolation Details (GND Isolation)

> [!IMPORTANT]
> The **TLP222A #2 (Pin A3)** does not cut the PWM signal; instead, it **physically connects/disconnects the PWM-to-DAC module's GND pin**. This ensures a **true 0.00V** at the analog output to the welder when the pedal is at rest.

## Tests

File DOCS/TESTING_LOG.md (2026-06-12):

# TESTING AND TROUBLESHOOTING LOG

This document chronologically records the problems encountered, hypotheses proposed, and solutions applied during the development of the **Wireless Welder Pedal** firmware.

---

## PHASE 1: Screen Stabilization and Basic Trigger (v7.0 - v7.2)
*   **Initial State:** The trigger worked (sent 0% - 100% PWM), but the OLED screen rendering using heavy bitmaps (`epd_bitmap`) caused memory crashes and graphical overlaps.
*   **Problem:** When the transmitter was disconnected, the screen showed the "X" over the previous icons.
*   **Solution:** The **Receiver (`receiver.ino`)** interface was rewritten to use pure geometric rendering (`drawRect`, `fillRect`). Mathematical parameters were standardized, achieving a perfect, fluid layout without memory loss.

---

## PHASE 2: Communication Crashes and I2C Loop (v7.6 - v8.7)
*   **Problem:** When connecting the VL53L4CD ToF sensor and pressing the trigger, the system disconnected completely (an "X" appeared on the welder's screen).
*   **Hypothesis 1 (Electrical Noise):** It was thought that physically turning on the laser (`XSHUT`) generated noise. Delays and an "I2C Shield" (I2C Ping) were implemented to ignore the sensor if it did not respond, preventing the program from hanging.
*   **Result:** The system stopped disconnecting when the trigger was pressed, but the laser still read "0%".
*   **Hypothesis 2 (I2C Buffer Limit):** The ATmega32u4 architecture was investigated. It was discovered that the official `STM32duino` library attempted to send the laser firmware in blocks larger than the 32-bytes allowed by the AVR `Wire` library, causing a silent infinite hang.
*   **Solution:** The code was migrated to the **"VL53L4CD by Pololu"** library, which is designed with automatic chunking and software timeouts, ensuring the chip never freezes.

---

## PHASE 3: Wireless Diagnostics and Voltage Drop (Brownout) (v9.0 - v9.2)
*   **Post-Pololu Problem:** Despite the library change, the sensor still reported 0%, and the transmitter board's USB port would randomly disconnect from the Arduino IDE when running the code.
*   **Diagnostic Hypothesis:** Since the USB disconnected and the Serial Monitor could not be used, a **"Wireless I2C Scanner" (v9.1)** was created. This firmware mapped I2C states to specific percentages sent via LoRa to the screen (0% = Dead, 51% = OK 0x29). The result was "0%", indicating the sensor was electrically dead at startup.
*   **Root Cause (Radio Brownout):** The power topology was analyzed. When powering the board **only via USB**, the internal 3.3V regulator suffered a massive voltage drop (Brownout) when the LoRa radio module attempted to transmit at maximum power (17dBm / ~120mA). 
    *   This voltage drop turned off the VL53L4CD sensor (which requires stable 3.3V) and reset the ATmega32u4 (disconnecting the USB).
*   **Applied Solution (v9.2):** 
    1. The LoRa radio was forced to operate at **Low Power (`LoRa.setTxPower(2)`)**.
    3. **Hardware Rule:** It was established that for continuous transmission testing or final use, the LiPo battery must be connected to absorb the current spikes that the USB cannot manage.

---

## PHASE 4: The XSHUT Pin Conflict (Final Awakening)
*   **Problem:** Despite stable voltage and the anti-freeze Pololu library, the I2C scanner still failed to detect the sensor (reading 0%).
*   **Hardware Hypothesis:** The orange wire (`XSHUT` / LPN) was connected to Pin 6 of the Arduino. If the Arduino could not pull that pin to a clean 3.3V (due to an internal conflict with the LoRa32u4 board, a shared pull-down resistor, or a pin current limit), the sensor remained eternally off in "Shutdown" mode.
*   **Definitive Test:** It was ordered to physically disconnect the orange wire (Pin 6) and leave the sensor's `XSHUT` pin floating.
*   **Result:** Immediate Success! The I2C scanner instantly detected the sensor at address `0x29` (showing 51% on the screen).
*   **Architectural Conclusion:** The AliExpress VL53L4CD modules have an internal pull-up resistor on the `XSH` pin. By leaving it disconnected, the sensor auto-ignites safely. Pin 6 of the LoRa32u4 board was choking this signal.
*   **Final Action:** All `XSHUT` pin control code was removed from the transmitter. The sensor now operates freely, commanded only by I2C read requests.

---

## PHASE 5: Final Calibration and Advanced Filtering (v10.3)
*   **Range Adjustment:** The working range was standardized to **15mm (100%) to 50mm (0%)**.
*   **Dual Filter (Median + EMA):**
    *   **Median Filter (5 samples):** Implemented to eliminate ±3mm reading noise (jitter). This filter ignores spikes and maintains the central value.
    *   **EMA Filter (0.4):** Applied over the median value to ensure smooth transitions.
*   **Standby Mode:** Automatic LoRa radio disconnection was added after 5 minutes of inactivity, with a **flashing Hourglass icon (100ms)** on the receiver to indicate this state.
*   **Latency Optimization:** The sensor timing budget was adjusted to 50ms and the transmission loop to 30ms.

---

## PHASE 6: OLED Interface Refinement and RSSI Calibration
*   **Geometric Interface (OLED):** The Receiver's screen design was updated using `drawRoundRect` (rounded corners) for the 4 information blocks (PWM, Antenna, Bat TX, Bat RX). Dynamic mathematical centering for the PWM percentage text was implemented, and the disconnection 'X' icon size was reduced.
*   **LoRa Antenna Calibration:** The RSSI signal mapping was adjusted. Since LoRa technology operates efficiently with very weak signals, a range of `-110dBm` (0 bars) to `-60dBm` (5 full bars) was established, achieving a realistic visual representation of link strength at normal working distances (5-10 meters).

---

## PHASE 7: TOF Sensor Reset and Lockup Prevention (v1.1 Patch)
*   **Problem:** The TOF laser sensor (VL53L4CD) would occasionally get stuck in a locked-up or disconnected state. Pressing the microcontroller's physical RESET button did not restore functionality, and the sensor remained dead until a complete power cycle (disconnecting the battery/USB) was performed.
*   **Root Cause:** The microcontroller's physical RESET button resets the ATmega32u4 but does not cut power to the 3.3V/5V rails. During reset, microcontroller pins enter a High-Z input state. Since the sensor was configured to pull up `XSHUT` (`PIN_LPN`), it remained powered and in its locked state without experiencing a hardware reset.
*   **Solution:** Implemented a hardware reset sequence at the start of `setup()` in the transmitter firmware. The `PIN_LPN` (XSHUT) pin is now explicitly pulled `LOW` (GND) for 50ms to force the TOF sensor to shut down, then returned to `INPUT` (High-Z) to let it boot cleanly, followed by a 50ms stabilization delay before initializing the library.

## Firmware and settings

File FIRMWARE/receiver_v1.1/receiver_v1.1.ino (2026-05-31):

#include <Adafruit_GFX.h>
#include <Adafruit_SSD1306.h>
#include <EEPROM.h>
#include <LoRa.h>
#include <SPI.h>
#include <Wire.h>
#include <avr/sleep.h>
#include <avr/wdt.h>

// Watchdog Interrupt Service Routine (ISR)
ISR(WDT_vect) {
  // Watchdog timed out (system froze) - Perform a clean software restart
  void(* resetFunc) (void) = 0;
  resetFunc();
}

/**
 * PROJECT: Wireless Welder Pedal v1.1 | RECEIVER
 * 
 * DESCRIPTION:
 * This firmware implements the architectural optimizations defined in DOCS/FIREWARE_OPTIMIZATION_PROMP.md.
 * Key enhancements over V1.0 include:
 * - 3-Byte Ultra-Lightweight LoRa Payload (40% reduction in Time-on-Air and latency).
 * - Linear mapping decompression of ToF distance (0..254 -> 10..150mm) and Standby flags.
 * - Hardware-compatible Battery ADC scaling (divided by 2 over-the-air, multiplied by 2 locally).
 * - Native preservation of V1.0 Failsafe, OLED, and EMA smoothing layers for maximum stability.
 */

// =============================================================
//                    USER CONFIGURATION
// =============================================================
const long FAILSAFE_LIMIT = 1000;        // Max wait time for signal
const unsigned long DEEP_SLEEP_MIN = 15; // Minutes before Deep Sleep
const int PEDAL_UP_MM = 60;              // Pedal up distance
const int PEDAL_DOWN_MM = 18;            // Pedal down distance
const uint32_t RX_BATTERY_CALIBRATION = 17850; // Physical battery voltage calibration for Receiver
const uint32_t TX_BATTERY_CALIBRATION = 23800; // Physical battery voltage calibration for Transmitter

// =============================================================
//                    HARDWARE PINOUT
// =============================================================
#define PIN_PWM 9
#define PIN_PWM_GND 6
#define PIN_REL1 A5
#define PIN_REL1_GND 10
#define PIN_REL2 A3
#define PIN_REL2_GND 12
#define PIN_BAT A0
#define PIN_MODE 0
#define PIN_MODE_GND 1
#define PIN_LED A1
#define PIN_LED_GND A2
#define PIN_BUZZER A4

#define EEPROM_ADDR_MODE 0
#define PWM_MAX_VAL 244 // System hardware limit for active welding PWM
#define SCREEN_WIDTH 128
#define SCREEN_HEIGHT 64

// GLOBAL VARIABLES
Adafruit_SSD1306 display(SCREEN_WIDTH, SCREEN_HEIGHT, &Wire, -1);

// Optimized 3-Byte LoRa Payload
struct __attribute__((packed)) PedalDataPayload {
  uint8_t laserM;  // 0..254 = mapped distance (10..150mm), 255 = STANDBY (999)
  uint8_t flags;   // Bit 0: switchClosed (trigger), Bits 1..7: unused
  uint8_t batRaw;  // Raw ADC battery reading divided by 4
};

// Reconstructed/Compatible struct to keep remaining V1.0 logic untouched
struct PedalData {
  uint16_t laserDist;
  bool switchClosed;
  uint16_t batV;
};

PedalData myPedal;
uint16_t localBatV = 0;
int lastRSSI = 0, currentPWM = 0, currentPwmMin = 0;
uint16_t lastValidLaserDist = 60; // Last laser distance recorded before shutdown
unsigned long lastReception = 0, lastActivity = 0;
float sT = 0, sR = 0; // Global battery smoothing variables to allow reset on wake
bool systemLocked = true, isStandby = false, outputsEnabled = false, powerState = true;

enum class SystemState {
  STARTING,
  SEARCHING,
  STANDBY,
  CONNECTED,
  DISCONNECTED,
  HOLDING
};
SystemState currentState = SystemState::STARTING;

// ASSETS
const unsigned char PROGMEM antenna_bitmap[] = {
    0x01, 0x00, 0x03, 0x80, 0x03, 0x80, 0x1b, 0xb0, 0x3b, 0xb8, 0x73, 0x9c,
    0x63, 0x8c, 0xe3, 0x8c, 0xc1, 0x06, 0xc0, 0x06, 0xc0, 0x06, 0xe0, 0x0e,
    0x60, 0x0c, 0x70, 0x18, 0x3c, 0x78, 0x1f, 0xf0, 0x07, 0xc0};
const unsigned char PROGMEM flash_bitmap[] = {
    0x00, 0x80, 0x00, 0x00, 0x80, 0x00, 0x01, 0x80, 0x00, 0x01, 0x80,
    0x00, 0x03, 0x80, 0x00, 0x03, 0x80, 0x00, 0x07, 0x80, 0x00, 0x07,
    0xfc, 0x00, 0x0f, 0xf8, 0x00, 0x0f, 0xf8, 0x00, 0x1f, 0xf0, 0x00,
    0x00, 0xf0, 0x00, 0x00, 0xe0, 0x00, 0x00, 0xe0, 0x00, 0x00, 0xc0,
    0x00, 0x00, 0xc0, 0x00, 0x00, 0x80, 0x00, 0x00, 0x80, 0x00};

// 'PBT Icon' (TX - PEDAL BATTERY), 26x17px
const unsigned char PROGMEM icon_TX[] = {
    0x00, 0x00, 0x00, 0x00, 0x1f, 0x0f, 0x8f, 0xc0, 0x1f, 0x8f, 0xcf, 0xc0,
    0x19, 0x8c, 0xc3, 0x00, 0x19, 0x8c, 0xc3, 0x00, 0x19, 0x8c, 0xc3, 0x00,
    0x19, 0x8c, 0xc3, 0x00, 0x1f, 0x8f, 0x83, 0x00, 0x1f, 0x0f, 0x83, 0x00,
    0x18, 0x0c, 0xc3, 0x00, 0x18, 0x0c, 0xc3, 0x00, 0x18, 0x0c, 0xc3, 0x00,
    0x18, 0x0c, 0xc3, 0x00, 0x18, 0x0f, 0xc3, 0x00, 0x18, 0x0f, 0x83, 0x00,
    0x00, 0x00, 0x00, 0x00, 0x00, 0x00, 0x00, 0x00};

// 'RBT Icon' (RX - RECEIVER BATTERY), 26x17px
const unsigned char PROGMEM icon_RX[] = {
    0x00, 0x00, 0x00, 0x00, 0x1f, 0x0f, 0x8f, 0xc0, 0x1f, 0x8f, 0xcf, 0xc0,
    0x19, 0x8c, 0xc3, 0x00, 0x19, 0x8c, 0xc3, 0x00, 0x19, 0x8c, 0xc3, 0x00,
    0x19, 0x8c, 0xc3, 0x00, 0x1f, 0x0f, 0x83, 0x00, 0x1f, 0x8f, 0x83, 0x00,
    0x19, 0x8c, 0xc3, 0x00, 0x19, 0x8c, 0xc3, 0x00, 0x19, 0x8c, 0xc3, 0x00,
    0x19, 0x8c, 0xc3, 0x00, 0x19, 0x8f, 0xc3, 0x00, 0x19, 0x8f, 0x83, 0x00,
    0x00, 0x00, 0x00, 0x00, 0x00, 0x00, 0x00, 0x00};

byte currentMode = 0;

class OutputPin {
  uint8_t pin;

public:
  OutputPin(uint8_t p) : pin(p) {}
  void begin() {
    pinMode(pin, OUTPUT);
    writeDigital(LOW);
  }
  void writeDigital(bool state) { digitalWrite(pin, state); }
  void writePWM(int val) { analogWrite(pin, val); }
};

class BuzzerAlarm {
  OutputPin buzzerPin;
  int buzzesRemaining = 0;
  bool isBuzzing = false;
  unsigned long lastToggleTime = 0;

public:
  BuzzerAlarm(uint8_t p) : buzzerPin(p) {}
  void begin() { buzzerPin.begin(); }

  void trigger(int count) {
    if (buzzesRemaining > 0)
      return;                    // Don't override ongoing alarm
    buzzesRemaining = count * 2; // Each buzz is an ON and an OFF phase
    isBuzzing = true;
    buzzerPin.writeDigital(HIGH);
    lastToggleTime = millis();
    buzzesRemaining--;
  }

  void update() {
    if (buzzesRemaining > 0) {
      if (millis() - lastToggleTime >= 1000) {
        lastToggleTime = millis();
        isBuzzing = !isBuzzing;
        buzzerPin.writeDigital(isBuzzing);
        buzzesRemaining--;
        if (buzzesRemaining == 0) {
          buzzerPin.writeDigital(LOW);
          isBuzzing = false;
        }
      }
    } else if (isBuzzing) {
      buzzerPin.writeDigital(LOW);
      isBuzzing = false;
    }
  }
};

OutputPin rel1(PIN_REL1);
OutputPin rel2(PIN_REL2);
OutputPin pwmOut(PIN_PWM);
BuzzerAlarm sysBuzzer(PIN_BUZZER);

// === 0. INITIALIZATION ===
void setup() {
  Serial.begin(115200);
  pinMode(PIN_LED, OUTPUT);
  digitalWrite(PIN_LED, HIGH);
  pinMode(PIN_LED_GND, OUTPUT);
  digitalWrite(PIN_LED_GND, LOW); // Virtual GND for Power Button LED
  pwmOut.begin();
  rel1.begin();
  rel2.begin();
  sysBuzzer.begin();
  pinMode(PIN_MODE, INPUT_PULLUP);
  pinMode(PIN_MODE_GND, OUTPUT);
  digitalWrite(PIN_MODE_GND, LOW); // Virtual GND for Mode button
  pinMode(PIN_PWM_GND, OUTPUT);
  digitalWrite(PIN_PWM_GND, LOW);  // Virtual GND for DAC logic ground
  pinMode(PIN_REL1_GND, OUTPUT);
  digitalWrite(PIN_REL1_GND, LOW);
  pinMode(PIN_REL2_GND, OUTPUT);
  digitalWrite(PIN_REL2_GND, LOW);

  currentMode = EEPROM.read(EEPROM_ADDR_MODE);
  if (currentMode > 4)
    currentMode = 0;
  currentPwmMin = currentMode * 61;

  activateFailsafe();
  if (display.begin(SSD1306_SWITCHCAPVCC, 0x3C)) {
    display.setRotation(1);
    display.clearDisplay();
    display.setTextSize(1);
    display.setCursor(17, 15);
    display.print(F("POWER"));
    display.setTextSize(2);
    display.setCursor(20, 30);
    display.print(F("ON"));
    display.display();
  }
  LoRa.setPins(8, 4, 7);
  if (LoRa.begin(433E6))
    LoRa.setSyncWord(0xF1);
  currentState = SystemState::SEARCHING;
  lastReception = millis();
  lastActivity = millis();
  // Setup complete
  bool usbConnected = (USBSTA & (1 << VBUS));
  if (!usbConnected) {
    MCUSR &= ~_BV(WDRF);
    WDTCSR |= _BV(WDCE) | _BV(WDE);
    WDTCSR = _BV(WDP2) | _BV(WDP1) | _BV(WDIE); // Capa 2: Activar Watchdog de 1.0s solo en modo autónomo (evita interferir con USB)
  }
}

// === 1. POWER MANAGEMENT ===
void sleepSystem() {
  wdt_disable(); // Desactivar Watchdog antes de dormir
  outputsEnabled = false;
  activateFailsafe();
  digitalWrite(PIN_LED, LOW);
  display.ssd1306_command(SSD1306_DISPLAYOFF);
  LoRa.sleep();

  // Disable USB controller completely before sleep (notifies host PC of clean disconnect)
  #if defined(USBCON)
  USBCON = 0;
  #endif

  ADCSRA &= ~(1 << ADEN); // Disable ADC safely by clearing only the Enable bit
  powerState = false;
  while (digitalRead(PIN_MODE) == LOW)
    delay(10);
}

void wakeSystem() {
  powerState = true;
  ADCSRA |= (1 << ADEN); // Re-enable ADC preserving original Arduino prescaler
  sT = 0; // Reset battery smoothing to snap immediately to real values on wake
  sR = 0;

  // Re-initialize USB controller cleanly from scratch
  #if defined(USBCON)
  USBDevice.attach();
  #endif

  digitalWrite(PIN_LED, HIGH);
  display.ssd1306_command(SSD1306_DISPLAYON);
  currentMode = EEPROM.read(EEPROM_ADDR_MODE);
  if (currentMode > 4)
    currentMode = 0;
  currentPwmMin = currentMode * 61;
  currentState = SystemState::SEARCHING;
  isStandby = false; // Reset standby flag to boot in active searching state
  lastReception = millis();
  lastActivity = millis();

  // Wake complete
  bool usbConnected = (USBSTA & (1 << VBUS));
  if (!usbConnected) {
    MCUSR &= ~_BV(WDRF);
    WDTCSR |= _BV(WDCE) | _BV(WDE);
    WDTCSR = _BV(WDP2) | _BV(WDP1) | _BV(WDIE); // Reactivar Watchdog en Modo Interrupción al despertar si no hay USB
  }
}

// === 2. MAIN LOOP ===
void loop() {
  if (!powerState) {
    ADCSRA &= ~(1 << ADEN); // Ensure ADC is OFF (preserving prescaler)
    set_sleep_mode(SLEEP_MODE_PWR_DOWN);
    sleep_enable();
    attachInterrupt(digitalPinToInterrupt(PIN_MODE), []() {}, LOW);
    sei();
    sleep_cpu();
    sleep_disable();
    ADCSRA |= (1 << ADEN); // Re-enable ADC preserving prescaler
    detachInterrupt(digitalPinToInterrupt(PIN_MODE));
    if (digitalRead(PIN_MODE) == LOW) {
      wakeSystem();
      while (digitalRead(PIN_MODE) == LOW)
        delay(10);
    }
    return;
  }

  // Main button check
  bool btn = (digitalRead(PIN_MODE) == LOW);
  static bool btnL = false;
  static unsigned long btnS = 0;
  if (btn && !btnL) {
    btnS = millis();
  }
  if (btn && (millis() - btnS > 2000)) {
    sleepSystem();
    btnL = false;
    return;
  }
  if (!btn && btnL && (millis() - btnS < 600)) {
    currentMode = (currentMode + 1) % 5;
    EEPROM.update(EEPROM_ADDR_MODE, currentMode);
    currentPwmMin = currentMode * 61;
  }
  btnL = btn;

  // Optimized Payload parsing & Reconstructed compatible struct values
  if (LoRa.parsePacket() == sizeof(PedalDataPayload)) {
    PedalDataPayload rxPayload;
    LoRa.readBytes((uint8_t *)&rxPayload, sizeof(PedalDataPayload));
    
    // Decode switch closed flag
    myPedal.switchClosed = (rxPayload.flags & 0x01) ? true : false;
    
    // Decode distance travel mapping
    if (rxPayload.laserM == 255) {
      myPedal.laserDist = 999; // Standby
    } else {
      // Reconstruct millimeter value: map 0..254 back to 10..150mm
      myPedal.laserDist = map(rxPayload.laserM, 0, 254, 10, 150);
    }
    
    // Reconstruct raw ADC battery voltage (divided by 4 on TX)
    myPedal.batV = (uint16_t)rxPayload.batRaw * 4;

    lastReception = millis();
    lastActivity = millis();
    lastRSSI = LoRa.packetRssi();
    isStandby = (myPedal.laserDist == 999);
    systemLocked = isStandby;
    outputsEnabled = !isStandby;
    if (isStandby)
      activateFailsafe();
    currentState = isStandby ? SystemState::STANDBY : SystemState::CONNECTED;
  }

  // Keep system awake if button is pressed (USB does not prevent sleep)
  if (btn) {
    lastActivity = millis();
  }

  // Hot-plug USB detection for IDE
  static bool lastVbusRx = false;
  bool currentVbusRx = (USBSTA & (1 << VBUS));
  if (currentVbusRx && !lastVbusRx) {
    USBDevice.detach();
    delay(500);
    USBDevice.attach();
  }
  lastVbusRx = currentVbusRx;

  if (millis() - lastActivity > (DEEP_SLEEP_MIN * 60000UL)) {
    sleepSystem();
    return;
  }

  unsigned long dt = millis() - lastReception;

  // Dynamic timeout: 1s for Active, 10s for Standby
  bool timedOut = (!isStandby && dt > FAILSAFE_LIMIT) || (isStandby && dt > 10000);

  if (timedOut) {
    activateFailsafe();
    outputsEnabled = false;
    systemLocked = true;
    // We preserve isStandby's state (retaining visual Standby parpadeo if we timed out from Standby)
    currentState = SystemState::DISCONNECTED;
  } else if (!isStandby && dt > 200) {
    currentState = SystemState::HOLDING;
  }

  if (outputsEnabled) {
    currentPWM = map(constrain(myPedal.laserDist, PEDAL_DOWN_MM, PEDAL_UP_MM),
                     PEDAL_UP_MM, PEDAL_DOWN_MM, currentPwmMin, PWM_MAX_VAL);
    pwmOut.writePWM(currentPWM);
    rel1.writeDigital(myPedal.switchClosed);
    rel2.writeDigital(myPedal.switchClosed);
  }

  readBatteries();
  updateDisplay();

  sysBuzzer.update();

  // LED status indicator (Blinks in Standby, solid ON when active)
  if (isStandby) {
    digitalWrite(PIN_LED, (millis() % 1500 < 1000) ? HIGH : LOW);
  } else {
    digitalWrite(PIN_LED, HIGH);
  }

  // Battery Alarm Logic
  static bool alarm10Triggered = false;
  static bool alarm5Triggered = false;

  int pTX = (currentState != SystemState::DISCONNECTED)
                ? map(constrain((int)sT, 3100, 4100), 3100, 4100, 0, 100)
                : 100;
  int pRX = map(constrain((int)sR, 3100, 4100), 3100, 4100, 0, 100);
  int lowestBat = min(pTX, pRX);

  if (lowestBat <= 5) {
    if (!alarm5Triggered) {
      sysBuzzer.trigger(5);
      alarm5Triggered = true;
      alarm10Triggered = true;
    }
  } else if (lowestBat <= 10) {
    if (!alarm10Triggered) {
      sysBuzzer.trigger(3);
      alarm10Triggered = true;
    }
    if (lowestBat > 7) {
      alarm5Triggered = false;
    }
  } else {
    if (lowestBat > 12) {
      alarm10Triggered = false;
      alarm5Triggered = false;
    }
  }
}

// === 3. HARDWARE CONTROL ===
void readBatteries() {
  static unsigned long lastBatRead = 0;
  if (millis() - lastBatRead < 500)
    return;
  lastBatRead = millis();

  ADMUX = _BV(REFS0) | _BV(MUX4) | _BV(MUX3) | _BV(MUX2) | _BV(MUX1);
  ADCSRA |= _BV(ADSC);
  while (bit_is_set(ADCSRA, ADSC))
    ;
  analogRead(PIN_BAT);
  delay(5); // Electrical quiet-period: prevents SPI/I2C noise from corrupting
            // high-impedance ADC sample capacitor
  localBatV = (uint16_t)(((uint32_t)analogRead(PIN_BAT) * RX_BATTERY_CALIBRATION) / 1000UL);
}

void activateFailsafe() {
  currentPWM = 0;
  pwmOut.writePWM(0);
  rel1.writeDigital(false);
  rel2.writeDigital(false);
}

// === 4. UI & DISPLAY ===
void updateDisplay() {
  static unsigned long lastD = 0;
  static bool lastStandbyState = false;

  // Atenuación automática del OLED en Standby
  if (isStandby != lastStandbyState) {
    if (isStandby) {
      display.ssd1306_command(SSD1306_SETCONTRAST);
      display.ssd1306_command(1); // Brillo mínimo
    } else {
      display.ssd1306_command(SSD1306_SETCONTRAST);
      display.ssd1306_command(255); // Brillo máximo
    }
    lastStandbyState = isStandby;
  }

  if (millis() - lastD < 50)
    return;
  lastD = millis();
  display.clearDisplay();
  int w = 62, h = 28, x_b = 1, half = 31, radius = 3;
  int ys[] = {2, 34, 66, 98};
  for (int y : ys) {
    display.drawRoundRect(x_b, y, w, h, radius, SSD1306_WHITE);
    display.drawFastVLine(x_b + half, y, h, SSD1306_WHITE);
  }

  display.drawBitmap(x_b + half / 2 - 9, 2 + h / 2 - 9, flash_bitmap, 18, 18, SSD1306_WHITE);
  int vP = (outputsEnabled) ? currentPWM : currentPwmMin;
  int pctP = (vP >= 244) ? 100 : map(vP, 0, PWM_MAX_VAL, 0, 100);
  if (myPedal.switchClosed && outputsEnabled) {
    display.fillRect(x_b + half + 1, 3, half - 2, h - 2, SSD1306_WHITE);
    display.setTextColor(SSD1306_BLACK);
  } else
    display.setTextColor(SSD1306_WHITE);
  int tx = (pctP < 10) ? 10 : (pctP < 100 ? 7 : 4);
  display.setTextSize(1, 2);
  display.setCursor(x_b + half + tx, 4 + (h - 16) / 2);
  display.print(pctP);
  display.print("%");

  if (!isStandby || (millis() % 1500 < 1000))
    display.drawBitmap(x_b + (half - 15) / 2, 34 + (h - 17) / 2, antenna_bitmap,
                       15, 17, SSD1306_WHITE);
  if (currentState == SystemState::DISCONNECTED) {
    display.setTextColor(SSD1306_WHITE);
    display.setTextSize(1);
    display.setCursor(x_b + half + 7, 34 + (h - 8) / 2 + 1);
    display.print(F("---"));
  } else {
    int sP = constrain(map(lastRSSI, -115, -75, 0, 100), 0, 100);
    int bA = map(sP, 0, 100, 0, 5);
    if (sP > 0 && bA == 0)
      bA = 1;
    for (int i = 0; i < 5; i++)
      if (i < bA)
        display.fillRect(x_b + half + 4 + i * 5,
                         34 + h - 4 - map(i, 0, 4, 4, 20), 3,
                         map(i, 0, 4, 4, 20), SSD1306_WHITE);
  }

  if (currentState != SystemState::DISCONNECTED) {
    uint16_t tV = (uint16_t)(((uint32_t)myPedal.batV * TX_BATTERY_CALIBRATION) / 1000UL);
    if (sT == 0)
      sT = tV;
    sT = 0.02 * tV + 0.98 * sT;
  }
  if (sR == 0)
    sR = localBatV;
  sR = 0.02 * localBatV + 0.98 * sR;

  auto drawBat = [&](int y, const char *L, float val, bool disc) {
    bool isTX = (strcmp(L, "TX") == 0);
    int icon_x = x_b + (half - 26) / 2, icon_y = y + (h - 17) / 2 + 1;

    if (isTX)
      display.drawBitmap(icon_x, icon_y, icon_TX, 26, 17, SSD1306_WHITE);
    else
      display.drawBitmap(icon_x, icon_y, icon_RX, 26, 17, SSD1306_WHITE);
    if (disc) {
      display.setTextColor(SSD1306_WHITE);
      display.setTextSize(1);
      display.setCursor(x_b + half + 7, y + (h - 8) / 2 + 1);
      display.print(F("---"));
    } else {
      int p = map(constrain((int)val, 3100, 4100), 3100, 4100, 0, 100);
      int b = 0;
      if (p >= 80)
        b = 5;
      else if (p >= 60)
        b = 4;
      else if (p >= 40)
        b = 3;
      else if (p >= 20)
        b = 2;
      else if (p > 0)
        b = 1;
      for (int i = 0; i < 5; i++)
        if (i < b && !(p <= 10 && i == 0 && (millis() / 500 % 2)))
          display.fillRect(x_b + half + 4 + i * 5, y + 4, 3, h - 8, SSD1306_WHITE);
    }
  };
  drawBat(66, "TX", sT, currentState == SystemState::DISCONNECTED);
  drawBat(98, "RX", sR, false);
  display.display();
}

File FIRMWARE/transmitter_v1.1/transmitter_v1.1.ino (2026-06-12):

#include <SPI.h>
#include <LoRa.h>
#include <VL53L4CD.h>
#include <Wire.h>
#include <avr/sleep.h>
#include <avr/wdt.h>

/**
 * PROJECT: Wireless Welder Pedal v1.1 | TRANSMITTER
 * 
 * DESCRIPTION:
 * This firmware implements the architectural optimizations defined in DOCS/FIREWARE_OPTIMIZATION_PROMP.md.
 * Key enhancements over V1.0 include:
 * - 3-Byte Ultra-Lightweight LoRa Payload (40% reduction in Time-on-Air and latency).
 * - Non-Blocking Asynchronous FSM (ACTIVE, STANDBY, DEEP_SLEEP) with Watchdog Heartbeats.
 * - Software DSP Filtering (Median + EMA) applied to ToF raw distance prior to transmission.
 * - True Deep Sleep (SLEEP_MODE_PWR_DOWN) waking exclusively via PCINT hardware interrupts.
 */

// =============================================================
//                    USER CONFIGURATION
// =============================================================
const unsigned long STANDBY_MIN = 3;     // Minutes before Laser Standby
const unsigned long DEEP_SLEEP_MIN = 10; // Minutes before Deep Sleep
const unsigned long WAKE_UP_SAFE_TIME = 1; // SECONDS to ignore trigger after wake up
const int LORA_TX_POWER = 20; // Tx Power (2 to 20 dBm). 5 is recommended for workshop.

// =============================================================
//                    HARDWARE PINOUT
// =============================================================
#define PIN_SWITCH 11
#define PIN_SWITCH_GND 10
#define PIN_LED A3
#define PIN_LED_GND A4
#define PIN_BAT A0
#define PIN_MODE A1
#define PIN_MODE_GND A5
#define PIN_LPN 6 // Low Power (XSHUT) pin

// GLOBAL OBJECTS & STATE
VL53L4CD sensor;

// Optimized 3-Byte LoRa Payload
struct __attribute__((packed)) PedalData {
  uint8_t laserM;  // 0..254 = mapped distance (10..150mm), 255 = STANDBY/999
  uint8_t flags;   // Bit 0: switchClosed (trigger), Bits 1..7: unused
  uint8_t batRaw;  // Raw ADC battery reading divided by 4 (preserves RX calibration)
};

PedalData myPedal = {254, 0, 0}; // Mapped distance 254 (150mm inactive default)
bool laserInitialized = false, isSleeping = false, powerState = true, laserRunning = false;
unsigned long lastActivityTime = 0, lastTxTime = 0, lastHeartbeat = 0;
unsigned long wakeUpTime = 0;
uint16_t buffer[3] = {150, 150, 150};
int bufIdx = 0;
float smoothedDist = 150.0;

// Global Button State
bool btnLastState = false;
unsigned long btnStartTime = 0;
uint8_t standbyCycles = 0; // 500ms cycle counter for synchronized standby blinking

// === 0. INITIALIZATION ===
void setup() {
  delay(3000); // USB Grace Period for IDE recognition
  Serial.begin(115200);
  pinMode(PIN_MODE, INPUT_PULLUP);
  pinMode(PIN_MODE_GND, OUTPUT);
  digitalWrite(PIN_MODE_GND, LOW);
  pinMode(PIN_SWITCH, INPUT_PULLUP);
  pinMode(PIN_SWITCH_GND, OUTPUT);
  digitalWrite(PIN_SWITCH_GND, LOW);
  pinMode(PIN_LED, OUTPUT);
  pinMode(PIN_LED_GND, OUTPUT);
  digitalWrite(PIN_LED_GND, LOW);
  
  // Force a hardware reset of the TOF sensor by pulling XSHUT LOW
  pinMode(PIN_LPN, OUTPUT);
  digitalWrite(PIN_LPN, LOW);
  delay(50); // Keep LOW for 50ms to ensure reset
  pinMode(PIN_LPN, INPUT); // Startup in High-Z (Power ON via sensor pull-up)
  delay(50); // Wait for sensor to boot after reset
  
  pinMode(5, OUTPUT);
  digitalWrite(5, HIGH);
  delay(500);
  digitalWrite(PIN_LED, HIGH);

  LoRa.setPins(8, 4, 7);
  if (LoRa.begin(433E6)) {
    LoRa.setSyncWord(0xF1);
    LoRa.setTxPower(LORA_TX_POWER);
  }

  Wire.begin();
  Wire.setClock(100000);

  sensor.setTimeout(150);
  if (sensor.init()) {
    sensor.setRangeTiming(20, 0);
    laserInitialized = true;
  }

  lastActivityTime = millis();
  wakeUpTime = millis();
}

void sleepSystem() {
  if (laserRunning) {
    sensor.stopContinuous();
    laserRunning = false;
  }

  // Power down peripherals
  LoRa.sleep();

  // I2C Pins to INPUT to avoid leakage
  pinMode(2, INPUT);
  pinMode(3, INPUT);

  // Turn OFF Laser (Open Drain Logic: LOW = OFF)
  pinMode(PIN_LPN, OUTPUT);
  digitalWrite(PIN_LPN, LOW);

  digitalWrite(5, LOW);
  digitalWrite(PIN_LED, LOW);

  // Disable USB controller completely before sleep (notifies host PC of clean disconnect)
  #if defined(USBCON)
  USBCON = 0;
  #endif

  ADCSRA &= ~(1 << ADEN); // Disable ADC safely by clearing only the Enable bit
  powerState = false;
  isSleeping = false;
}

void wakeSystem() {
  powerState = true;
  ADCSRA |= (1 << ADEN); // Re-enable ADC preserving original Arduino prescaler
  wakeUpTime = millis();

  // Re-initialize USB controller cleanly from scratch
  #if defined(USBCON)
  USBDevice.attach();
  #endif

  // Turn ON Laser (Open Drain Logic: INPUT = High-Z = ON via sensor pull-up)
  pinMode(PIN_LPN, INPUT);

  digitalWrite(5, HIGH);
  digitalWrite(PIN_LED, HIGH);
  delay(500); // Wait for sensor to boot

  Wire.begin(); // Hardware I2C reset
  Wire.setClock(100000);
  if (sensor.init()) {
    sensor.setRangeTiming(20, 0);
    laserInitialized = true;
  }

  LoRa.idle();
  lastActivityTime = millis();
  btnLastState = false;
  btnStartTime = 0;
  laserRunning = false;
}

void enterDeepSleep() {
  set_sleep_mode(SLEEP_MODE_PWR_DOWN);
  sleep_enable();
  int intPin = digitalPinToInterrupt(PIN_MODE);
  if (intPin != NOT_AN_INTERRUPT) {
    attachInterrupt(intPin, []() {}, LOW);
  }
  PCMSK0 |= (1 << PCINT7);
  PCICR |= (1 << PCIE0);
  sei();
  sleep_cpu();
  sleep_disable();
  if (intPin != NOT_AN_INTERRUPT) {
    detachInterrupt(intPin);
  }
  PCICR &= ~(1 << PCIE0); // Disable Pin Change Interrupts so they don't fire during normal operation
}

EMPTY_INTERRUPT(PCINT0_vect); // Handle wake-up interrupt safely without crashing
ISR(WDT_vect) {} // Handle WDT interrupt for Standby wake-up
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

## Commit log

2026-05-16 Initial commit: Reorganized Monorepo structure for LoRa32u4
    [AXLE.SLDPRT, BASE-COVER.SLDPRT, BASE.SLDPRT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]
2026-05-17 Update V1.0: Extreme power saving, ADC prescaler fix, LPN control, and stable battery interpretation
2026-05-17 Release V1.0: Precise battery calibration, OLED stabilization, sleep safety threshold and buzzer battery notifications
2026-05-17 Feature: Add dynamic copy-paste calibration suggestions to Serial telemetry
2026-05-17 Docs: Update calibration instructions comment in receiver.ino
2026-05-17 Refactor: Simplify Serial logs and calibrate output suggestions to pure UL values
2026-05-17 Feature: Add dynamic interactive pedal distance limits calibration assistant
2026-05-17 Refactor: Rename battery calibration constants to RX_BATTERY_CALIBRATION and TX_BATTERY_CALIBRATION, translate comments to English, simplify pedal calibration logs
2026-05-17 Docs: Simplify calibration note comment, removing obsolete multimeter mention
2026-05-17 Docs: Add pedal distance calibration note comment in receiver.ino
2026-05-17 Refactor: Move PWM_MAX_VAL out of USER CONFIGURATION to system hardware definitions
2026-05-17 Feature: Add +1mm safety dead-zone buffer to suggested PEDAL_DOWN_MM calibration constant
2026-05-17 Feature: Automatically reset calibration min/max limits when Serial Monitor is closed and reopened
2026-05-17 Refactor: Delete obsolete raw telemetry lines, keeping only direct copy-pasteable calibration definitions in Serial Monitor
2026-05-17 Refactor: Add 3-cycle pedal calibration counter, 5-sample battery averaging, and remove UL suffixes
2026-05-17 Refactor: Implement EMA filter for calibration, isolate with if (Serial), and show live distance metrics
2026-05-17 Release V1.0: Hardware stabilization (100kHz I2C), circular battery buffers, locked battery calibration, and multitrigger resets
2026-05-17 Refactor: Simplify receiver and transmitter firmware to stable V1.0 without Serial telemetry/calibration
2026-05-17 Feat: Add official V1.1 firmware with 3-byte payload optimization, non-blocking FSM, and software filtering
2026-05-21 refactor(firmware,docs): migrate transmitter power to M16 momentary switch on A1-A4 and clean up wiring
    [AXLE.SLDPRT, BASE-COVER.SLDPRT, BASE.SLDPRT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]
2026-05-22 Update transmitter EMA filtering, battery telemetry calibration, low voltage cutoff, and hardware pinout to A5
2026-05-24 Implement Hardware Watchdog (WDT) and I2C timeouts on Receiver for high-speed EMI recovery
    [receiver_v1.1.ino]
2026-05-24 Remove setWireTimeout to support older Adafruit AVR Wire library versions
2026-05-24 Upgrade battery alarm logic to 3 levels using exact millivolt thresholds
2026-05-24 Switch Receiver Watchdog to non-resetting Interrupt Mode with software restart to preserve native USB uploading
    [receiver_v1.1.ino]
2026-05-31 Refactor: Restore stable USB uploads and sleep battery charging capability on transmitter v1.1
2026-06-12 fix(transmitter): implement TOF hardware reset & sync docs
    [transmitter_v1.1.ino]
